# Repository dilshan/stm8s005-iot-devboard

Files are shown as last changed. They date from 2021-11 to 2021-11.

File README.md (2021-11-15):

# STM8S005C6T6 Ethernet development board

This is an Ethernet development board based on [STM8S005C6T6](https://www.st.com/resource/en/datasheet/stm8s005c6.pdf), designed specifically for IoT related applications. This development board consists of [ENC28J60](http://ww1.microchip.com/downloads/en/devicedoc/39662c.pdf), 10BASE-T stand-alone Ethernet controller, [CH340G](https://cdn.sparkfun.com/datasheets/Dev/Arduino/Other/CH340DS1.PDF), USB serial interface, 2 LED indicators, and passive buzzer unit.

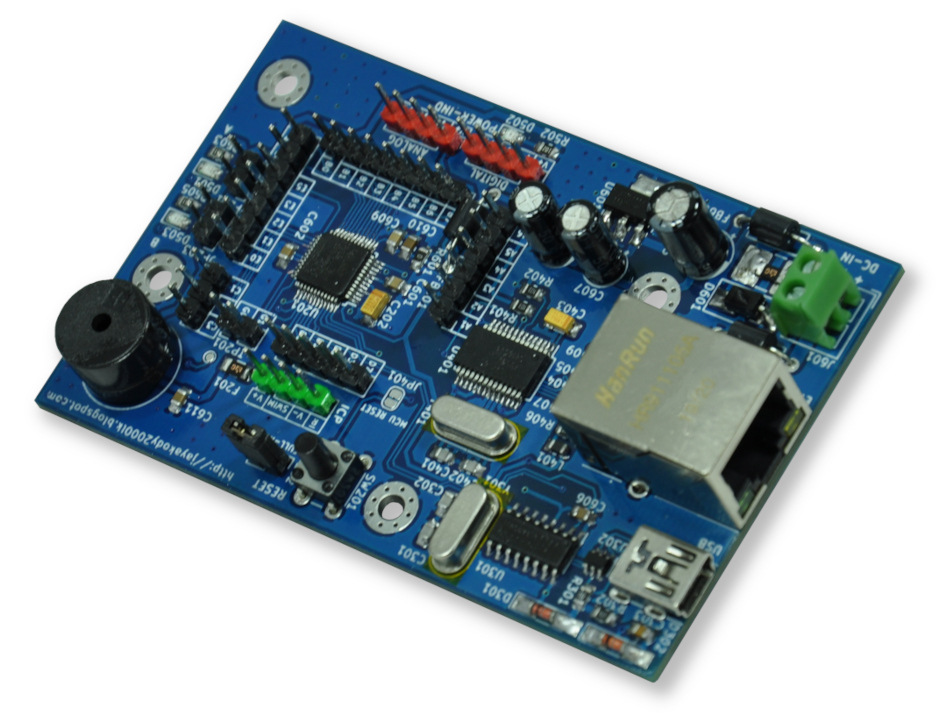
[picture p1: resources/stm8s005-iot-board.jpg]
STM8S005C6T6 Ethernet development board


The firmware framework for this development board has been developed using [SDCC](http://sdcc.sourceforge.net/). To enable IPv4 support, we convert the [EtherCard](https://github.com/njh/EtherCard) driver, which is available for the *Arduino* platform. The current version of this driver supports all other *EtherCard* functions except TCP support.

In the given design, the SPI terminals of the MCU are connected to the ENC28J60 Ethernet controller. All SPI terminals, such as *MISO* / *PC7*, *MOSI* / *PC6*, and *SCK* / *PC5*, are connected directly to the Ethernet controller. In addition, the *PC4* terminal of the MCU is used as ENC28J60, *CHIP-SELECT*. 

The CH340G USB serial interface is connected to the *UART2* terminals of the MCU. In STM8S005C6T6, the *UART2* is mapped to the *PD6* and *PD5* terminals of the MCU. The USB interface of this development board consists of the jack-sense feature. The jack-sense status can access from *PD7*.

The minor peripherals such as LED indicators and buzzer are connected to the *PORTD* of the MCU. The LED indicators are connected to terminals *PD0* and *PD1* and can be activated or deactivated via jumpers. The passive buzzer is connected to *PD4* and can run through the STM8 beep sound generator unit.

All peripherals of this development board are powered by a 3.3V supply. The recommended supply voltage for this development board is  5V to 9V.

In addition to the STM8S005C6T6, this development board supports the following STM8 series, LQFP48 packaged microcontrollers: [STM8S007C8T6](https://www.st.com/resource/en/datasheet/stm8s007c8.pdf), [STM8S207C8T6](https://www.st.com/resource/en/datasheet/stm8s207c8.pdf), and [STM8S105C6T6](https://www.st.com/resource/en/datasheet/stm8s105c6.pdf).

The schematic and PCB design of this project is released under the terms of [CERN-OHL-W Version 2.0](https://ohwr.org/cern_ohl_w_v2.pdf). The firmware framework is released under the terms of the [GNU GPL 2.0](https://github.com/dilshan/stm8s005-iot-devboard/blob/main/LICENSE) license.

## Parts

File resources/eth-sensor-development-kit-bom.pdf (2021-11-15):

Part ID | Value | Quantity
BZ501 | 12mm x 9.5mm Passive Buzzer | 1
| 0.1MFD – 0805 SMD Capacitor
| | 11
C202 | 1MFD / 10V – 1206 SMD Tantalum Capacitor | 1
C301, C302, C401, C402 | 22pF – 0805 SMD Capacitor | 4
C303, C304 | 0.01MFD – 0805 SMD Capacitor | 2
C403 | 10MFD / 10V – 1206 SMD Tantalum Capacitor | 1
C605 | | 1
C607, C608 | 10MFD / 25V – THT Radial Capacitor | 2
C610 | 1MFD / 10V – 0805 SMD Capacitor | 1
D301, D302 | 1N4148 – SMD MiniMELF | 2
D501 | LED (Green) – 0805 SMD | 1
D502 | LED (Red) – 0805 SMD | 1
D503 | LED (Yellow) – 0805 SMD | 1
D601 | SS24 – SMD SMB | 1
F201 | 100mA – 1206 SMD Polyfuse | 1
F601 | 500mA – 2816 SMD Polyfuse | 1
FB601, FB602, FB603 | 6.6mm – THT Axial Ferrite Bead | 3
J201 | 2-Pin – 2.54mm Female Header | 1
J202 | 7-Pin – 2.54mm Female Header | 1
J203 | 8-Pin – 2.54mm Female Header | 1
J204 | 6-Pin – 2.54mm Female Header | 1
J205 | 3-Pin – 2.54mm Female Header | 1
J206 | 5-Pin – 2.54mm Female Header | 1
J207 | 4-Pin – 2.54mm Male Header (Red) | 1
J301 | OMRON XM7D-0512 – USB Type B Mini Socket (THT) | 1
J401 | HR911105A Ethernet Socket with LEDs (THT) | 1
J601 | 2-Pin – 3.5mm Screw Terminal | 1
J602, J603 | 4-Pin – 2.54mm Male Header (Blue) | 2
JP201, JP202, JP203 | 2-Pin – 2.54mm Male Header | 3
L401 | 10uH – 0805 SMD Inductor | 1
Q501, Q502 | 2N7002 | 2
Q503 | MMBT3904 | 1
R201, R302, R401, R402 | 10K – 0805 SMD Resistor | 4
R301 | 6.8K – 0805 SMD Resistor | 1
R303, R403, R404, R502 | 1K – 0805 SMD Resistor | 4
R405 | 2.7K – 0805 SMD Resistor | 1
R406, R407, R408, R409 | 50R – 0805 SMD Resistor | 4
R501, R504 | 1M – 0805 SMD Resistor | 2
R503, R505 | 560R – 0805 SMD Resistor | 2
R506 | 2.2K – 0805 SMD Resistor | 1
R601 | 0R – 0805 SMD Resistor | 1
SW201 | 6mm x 6mm Tactile Switch | 1
U201 | STM8S005C6T6 | 1
U301 | CH340G | 1
U302 | USBLC6-2SC6 | 1
U401 | ENC28J60I-SS | 1
U601 | AMS1117-3.3 | 1
Y301 | 12MHz – HC49 Crystal | 1
Y401 | 25MHz – HC49 Crystal | 1

C201, C404, C405, C501, C601, C602, C603, C604, C606, C609, C611

100MFD / 25V – THT Radial Capacitor

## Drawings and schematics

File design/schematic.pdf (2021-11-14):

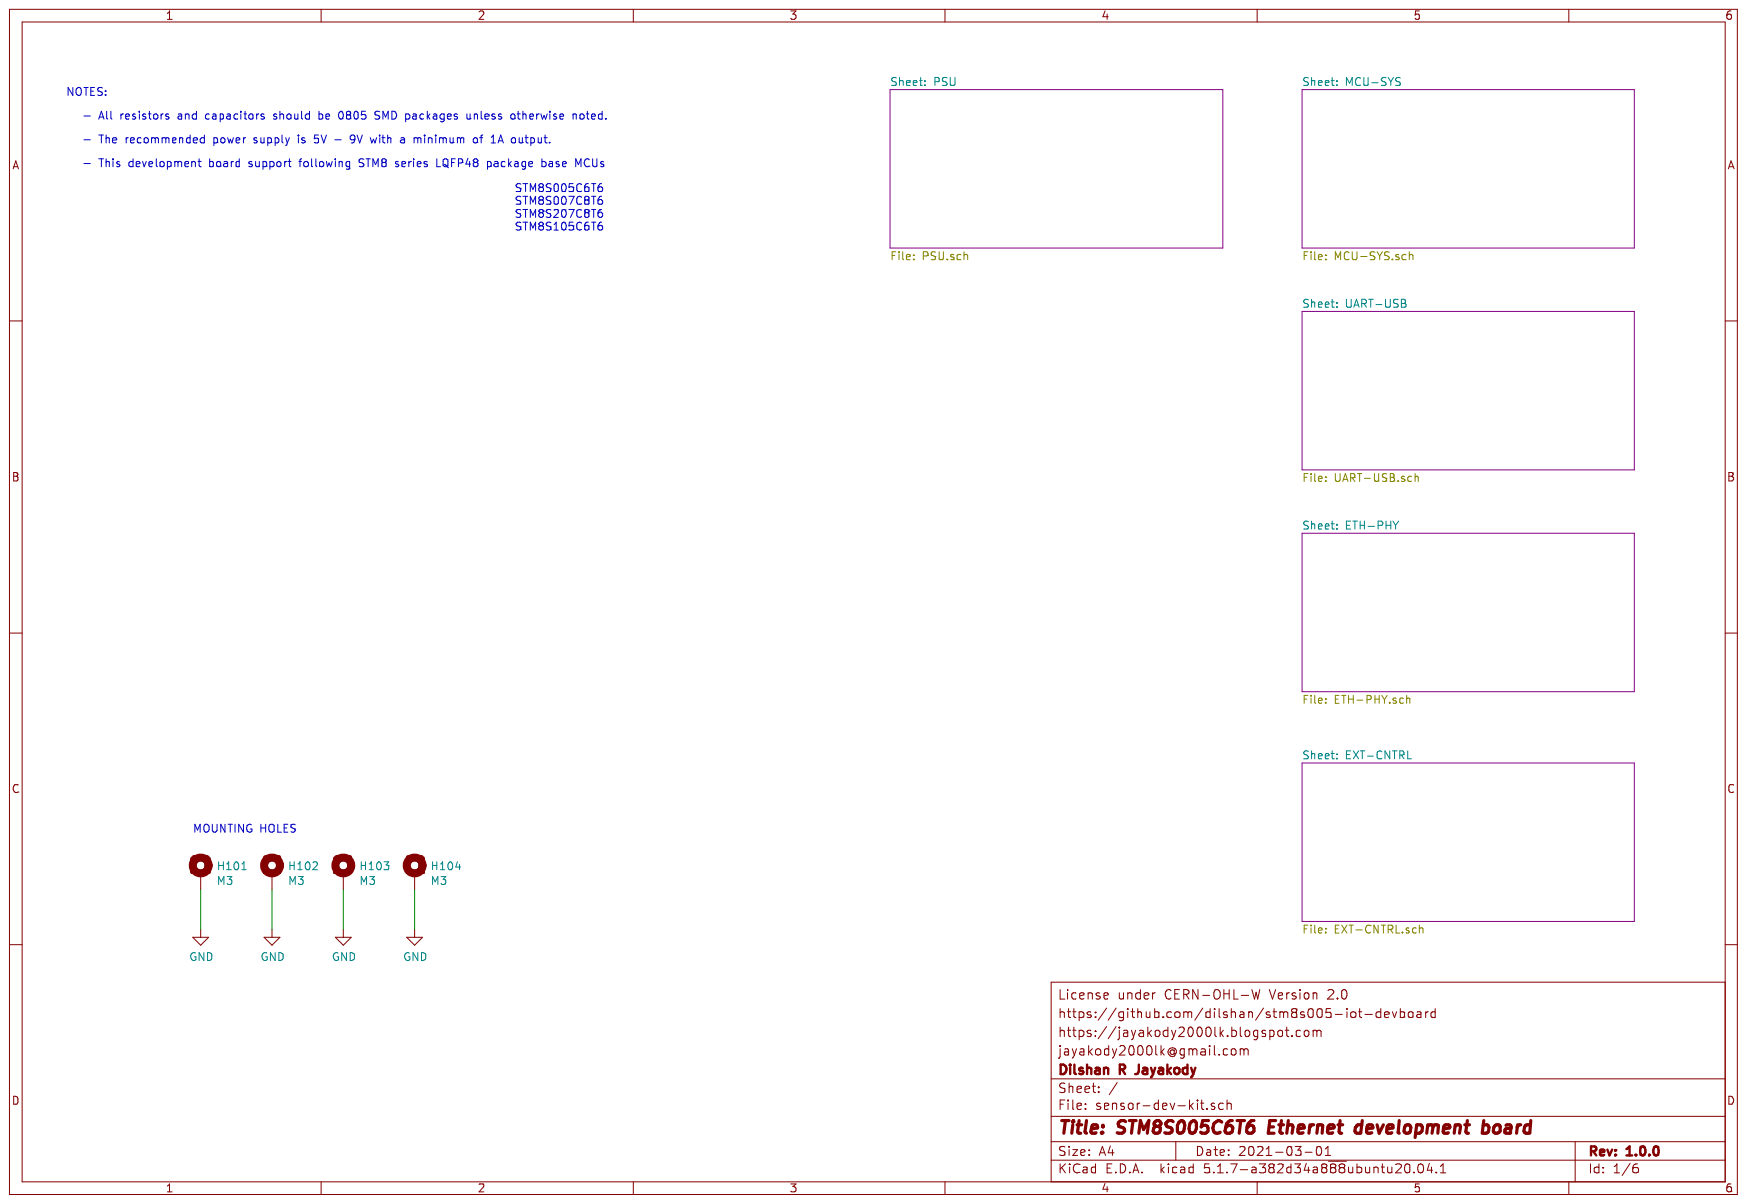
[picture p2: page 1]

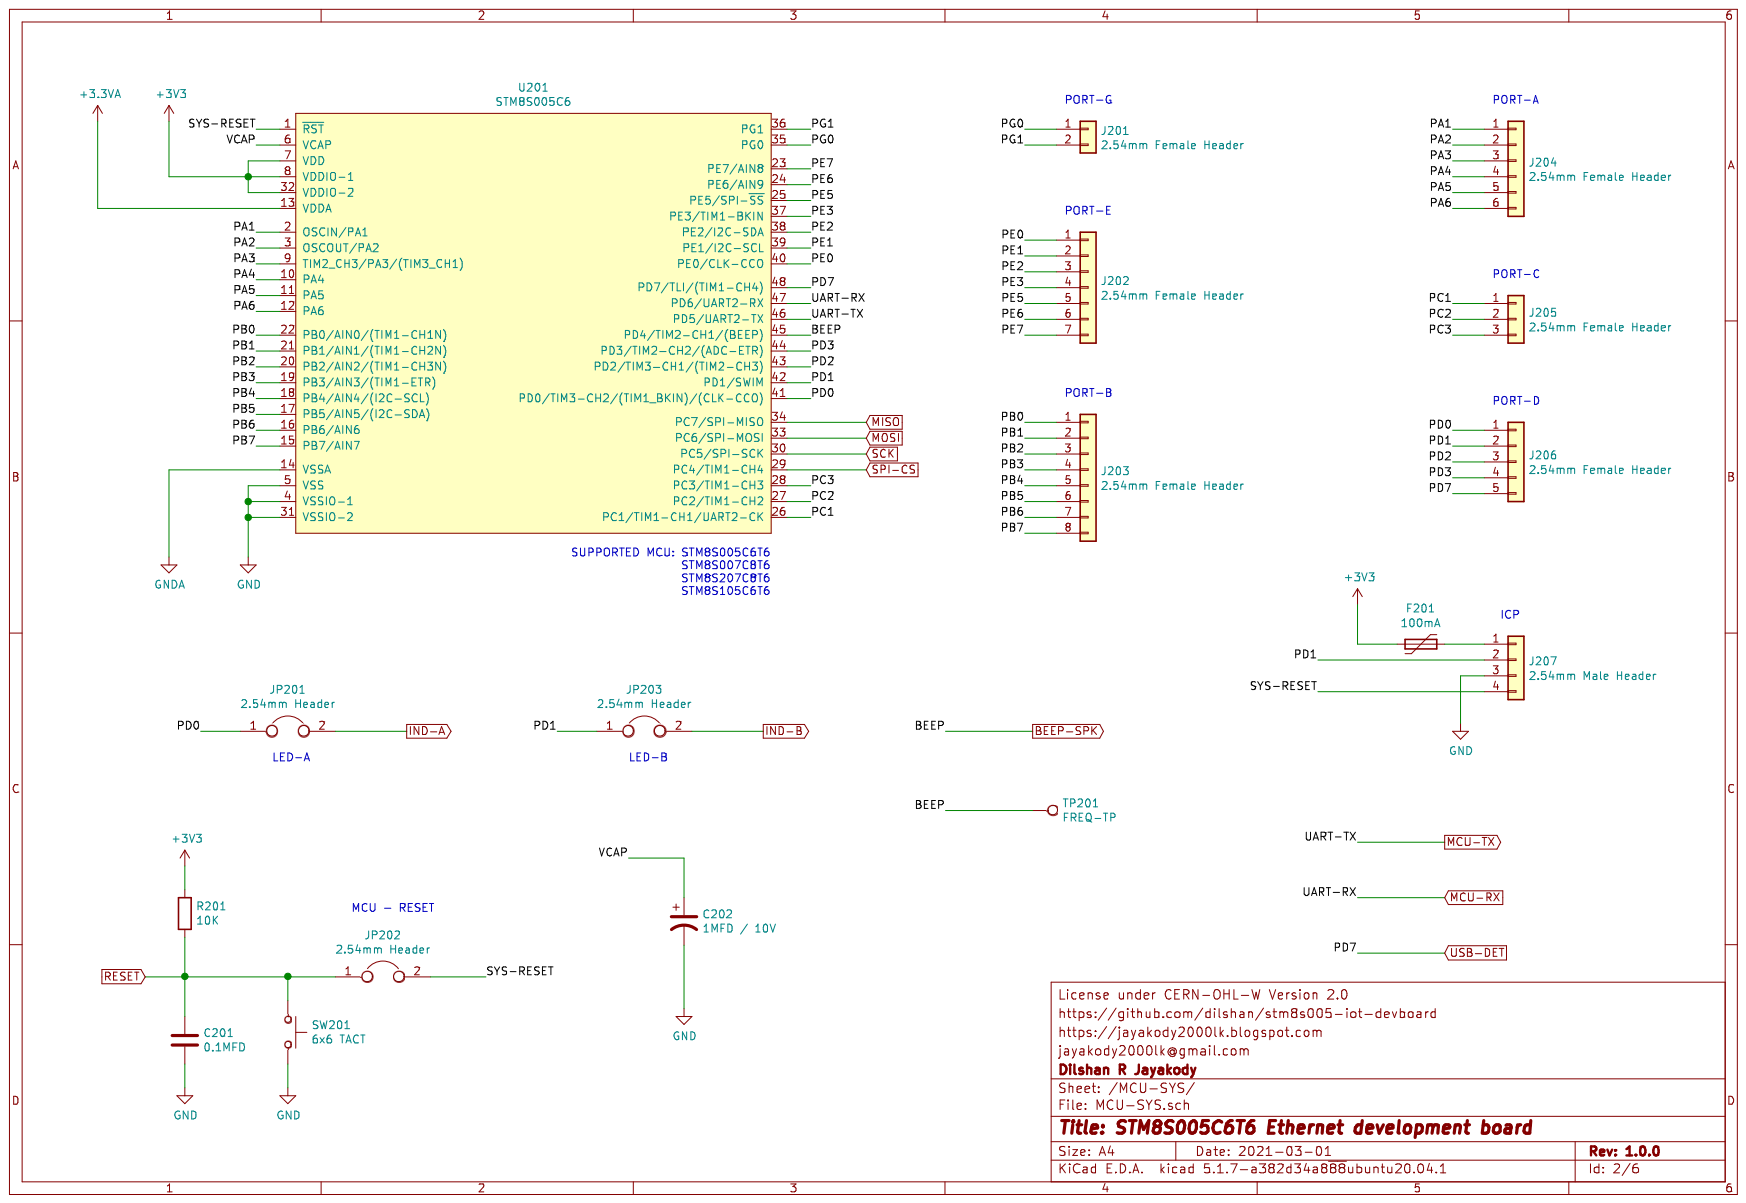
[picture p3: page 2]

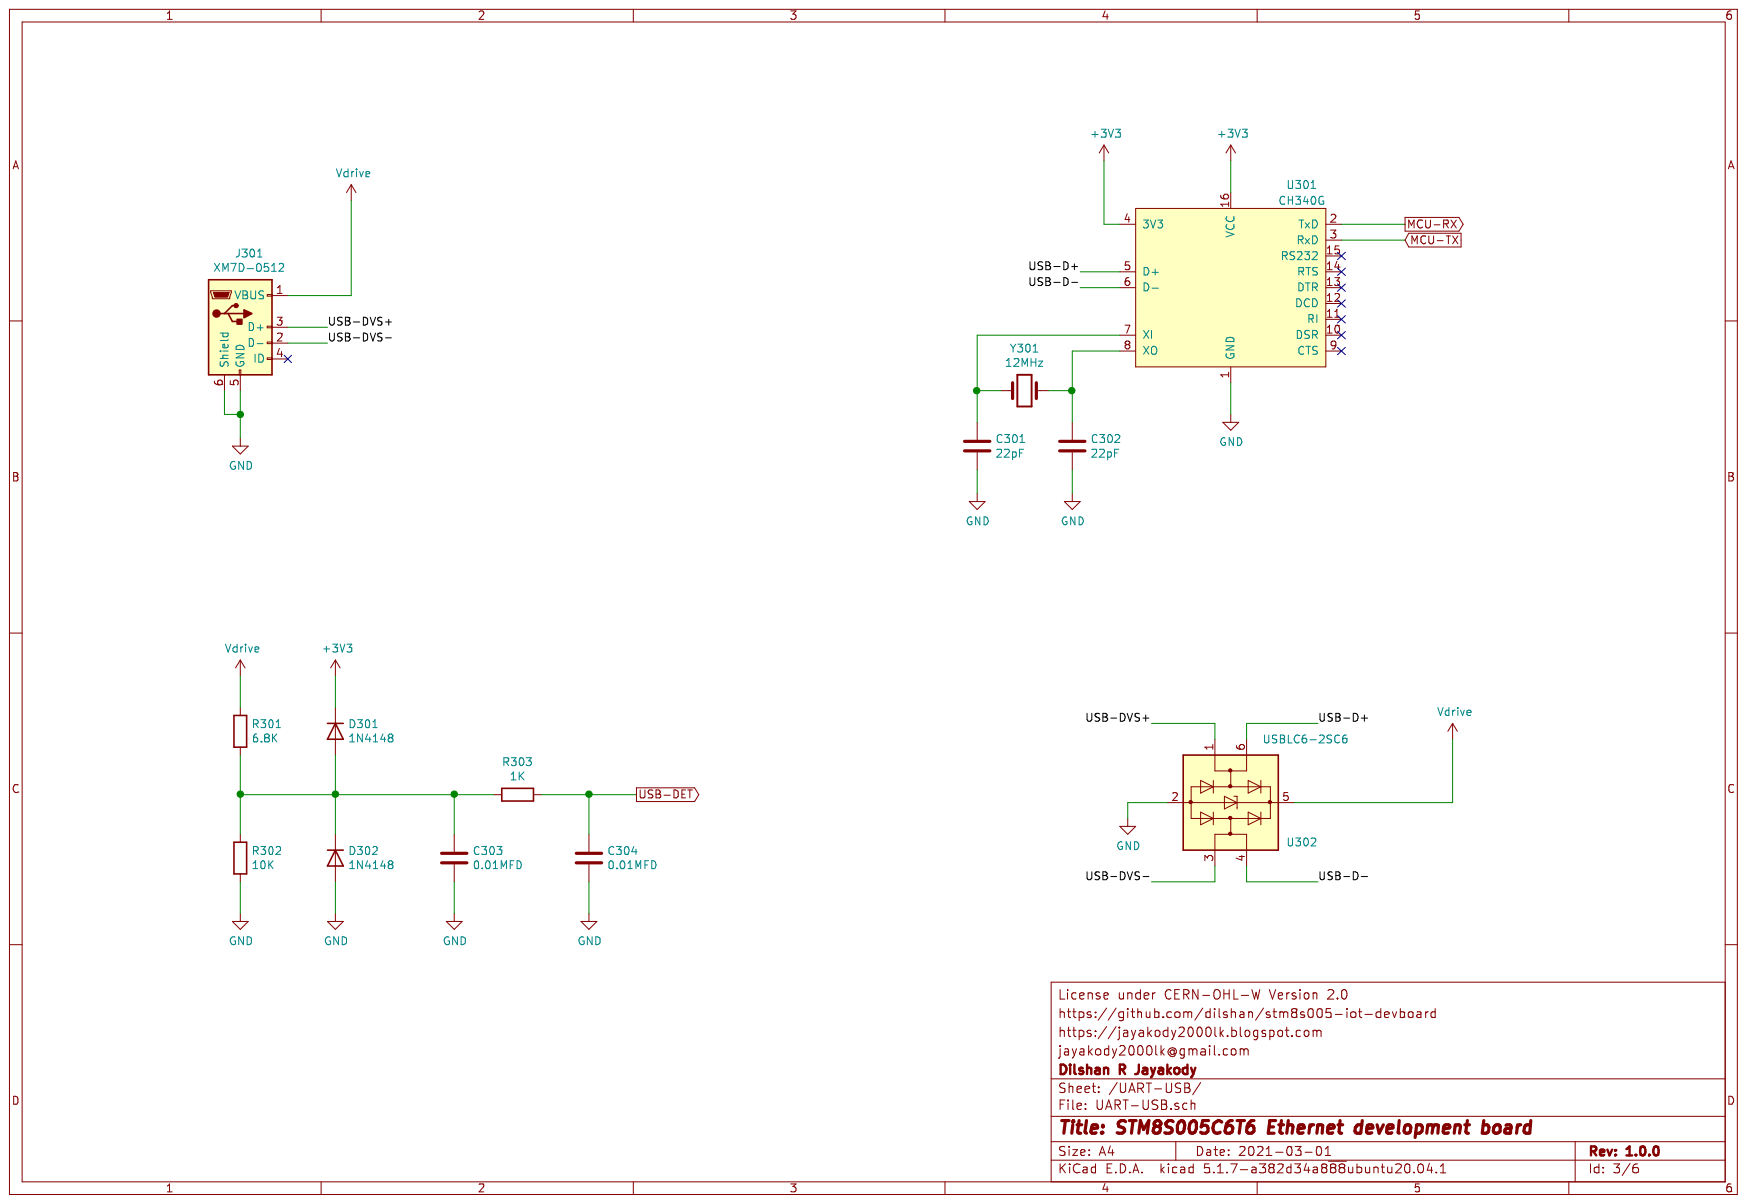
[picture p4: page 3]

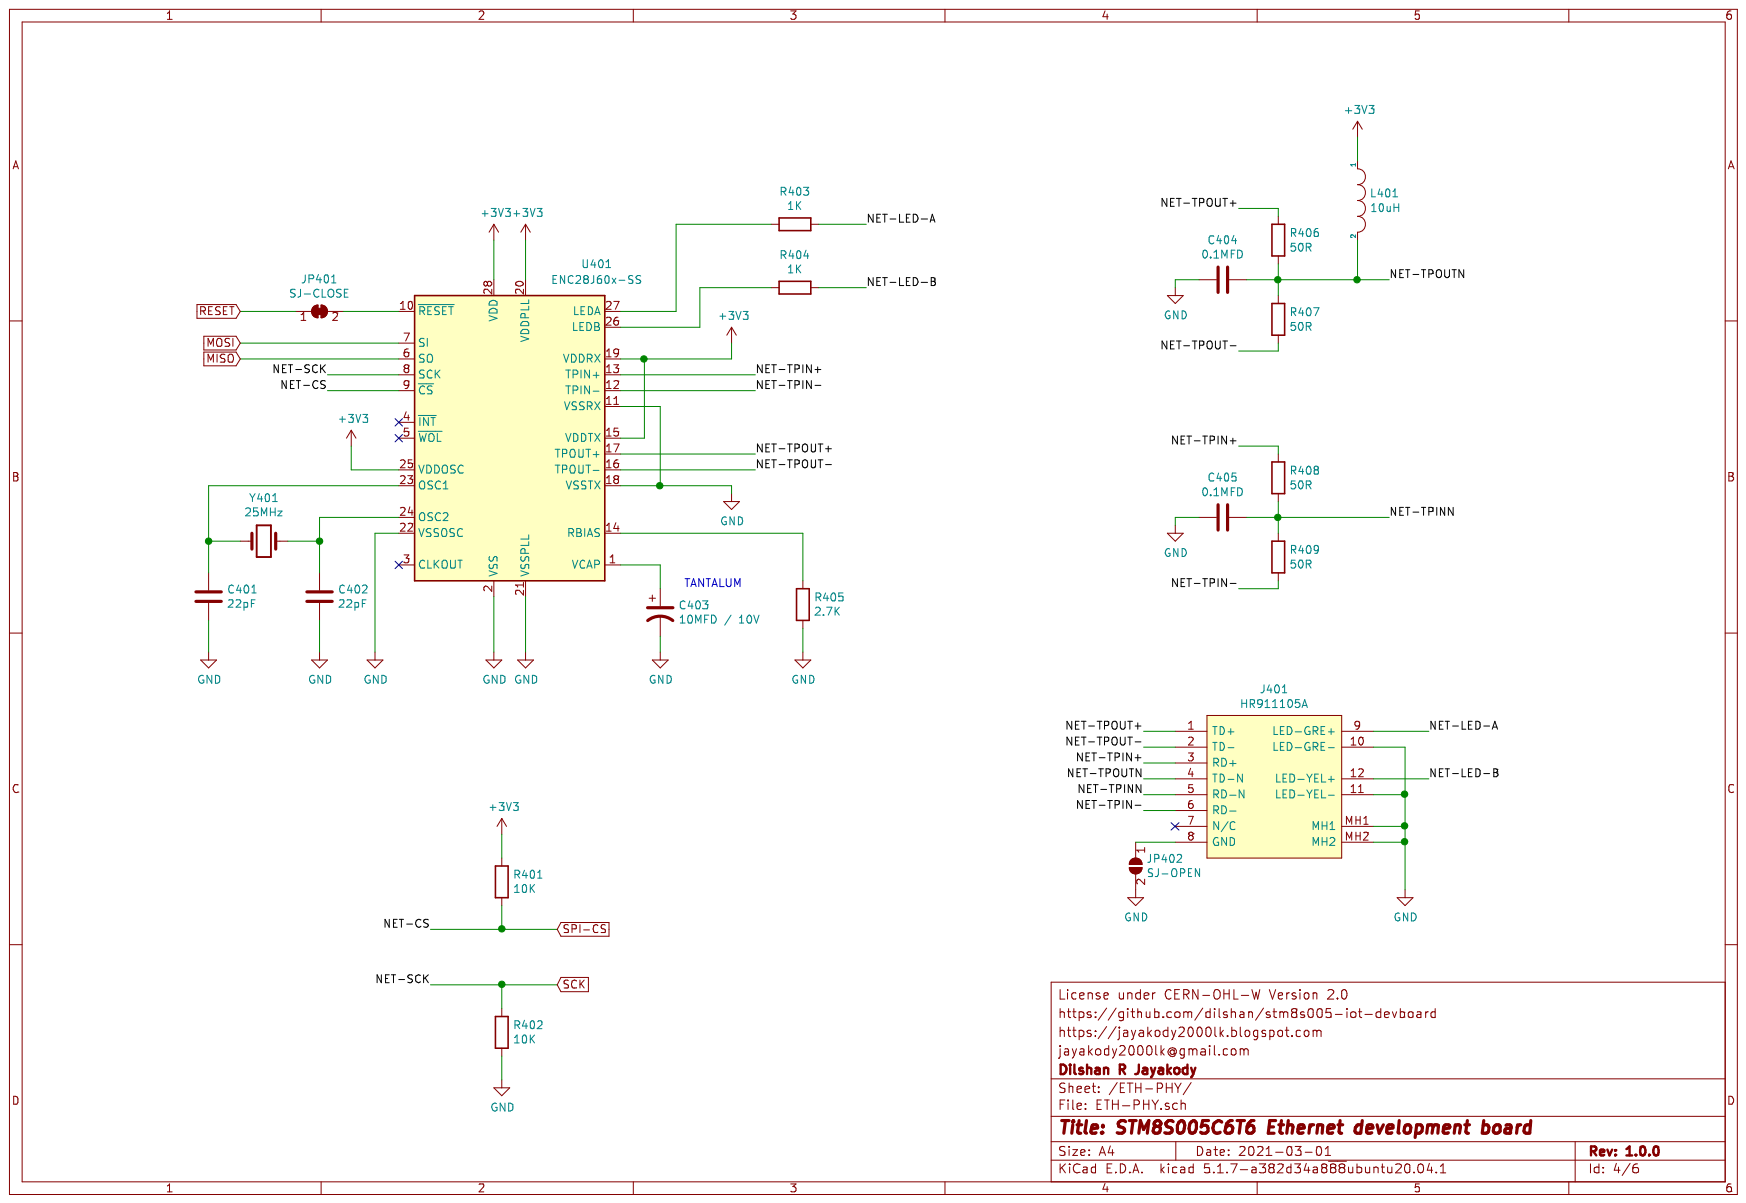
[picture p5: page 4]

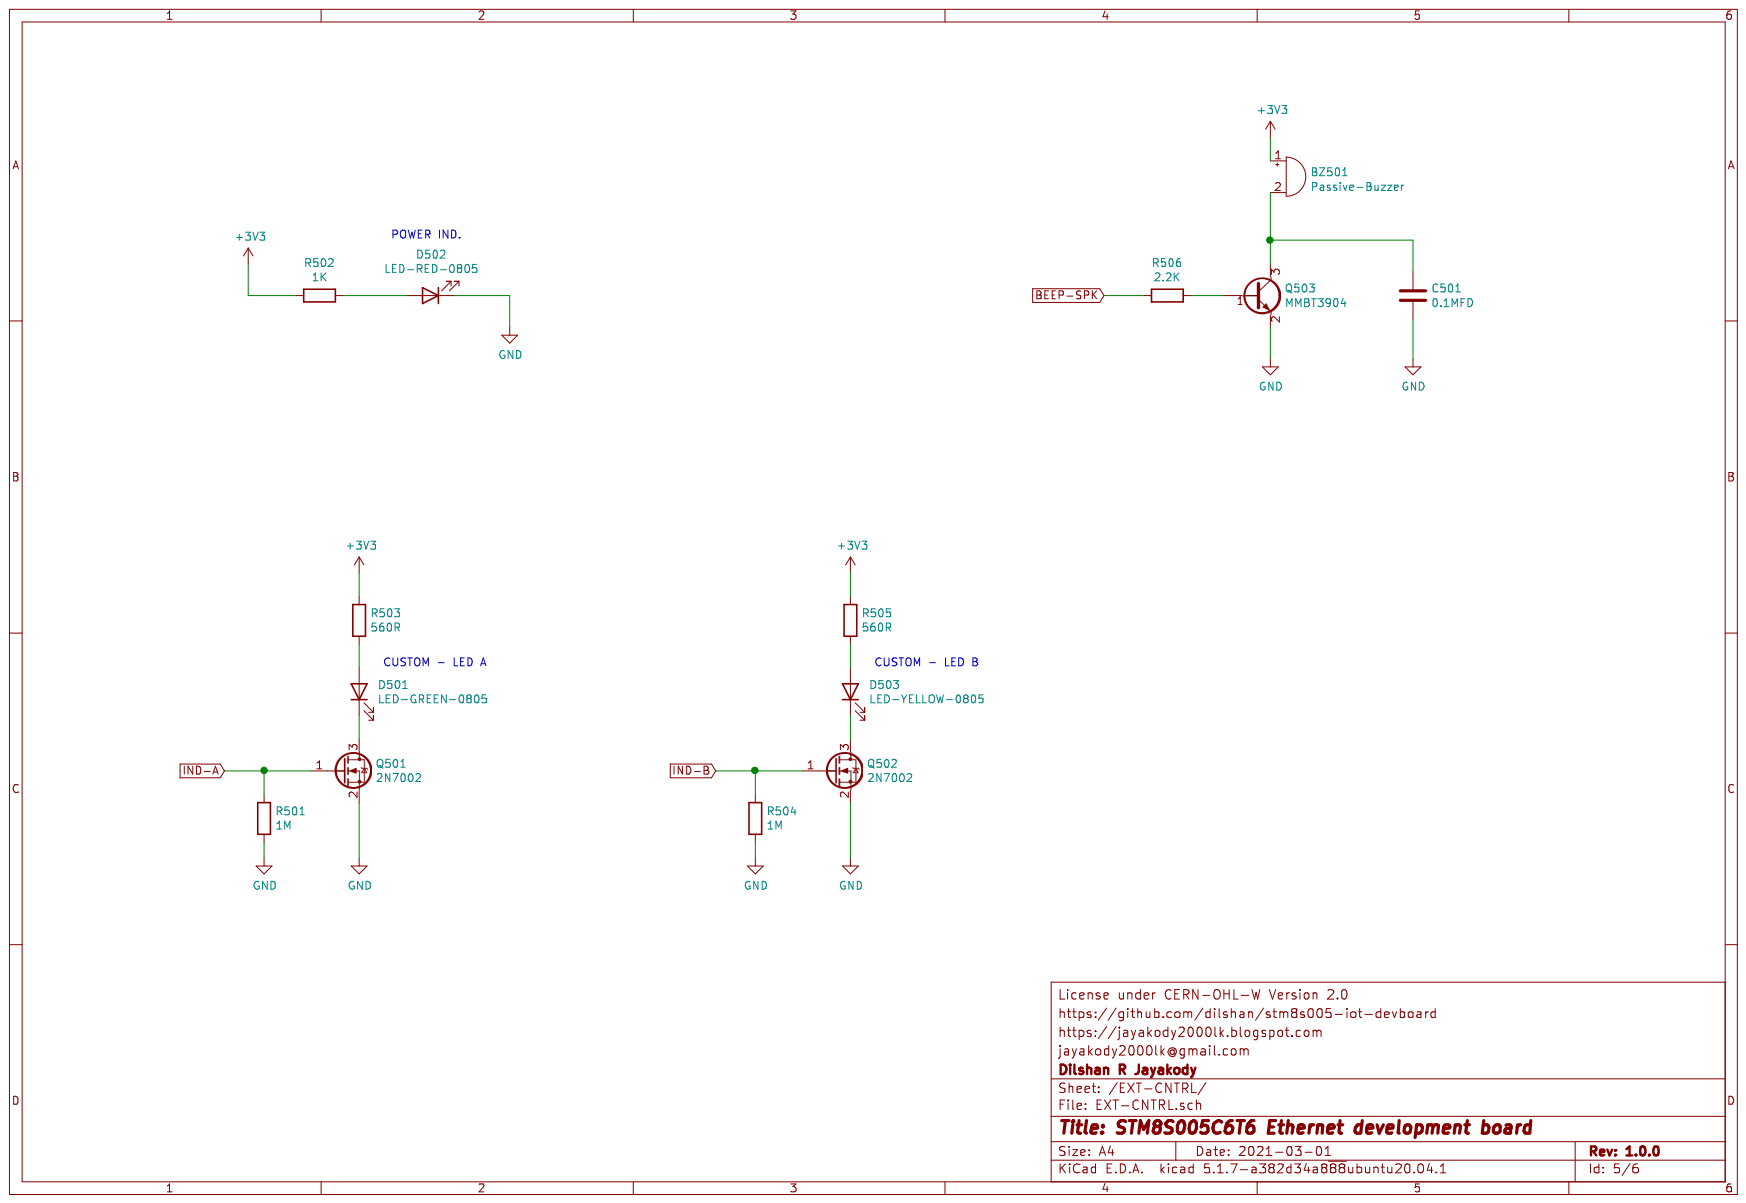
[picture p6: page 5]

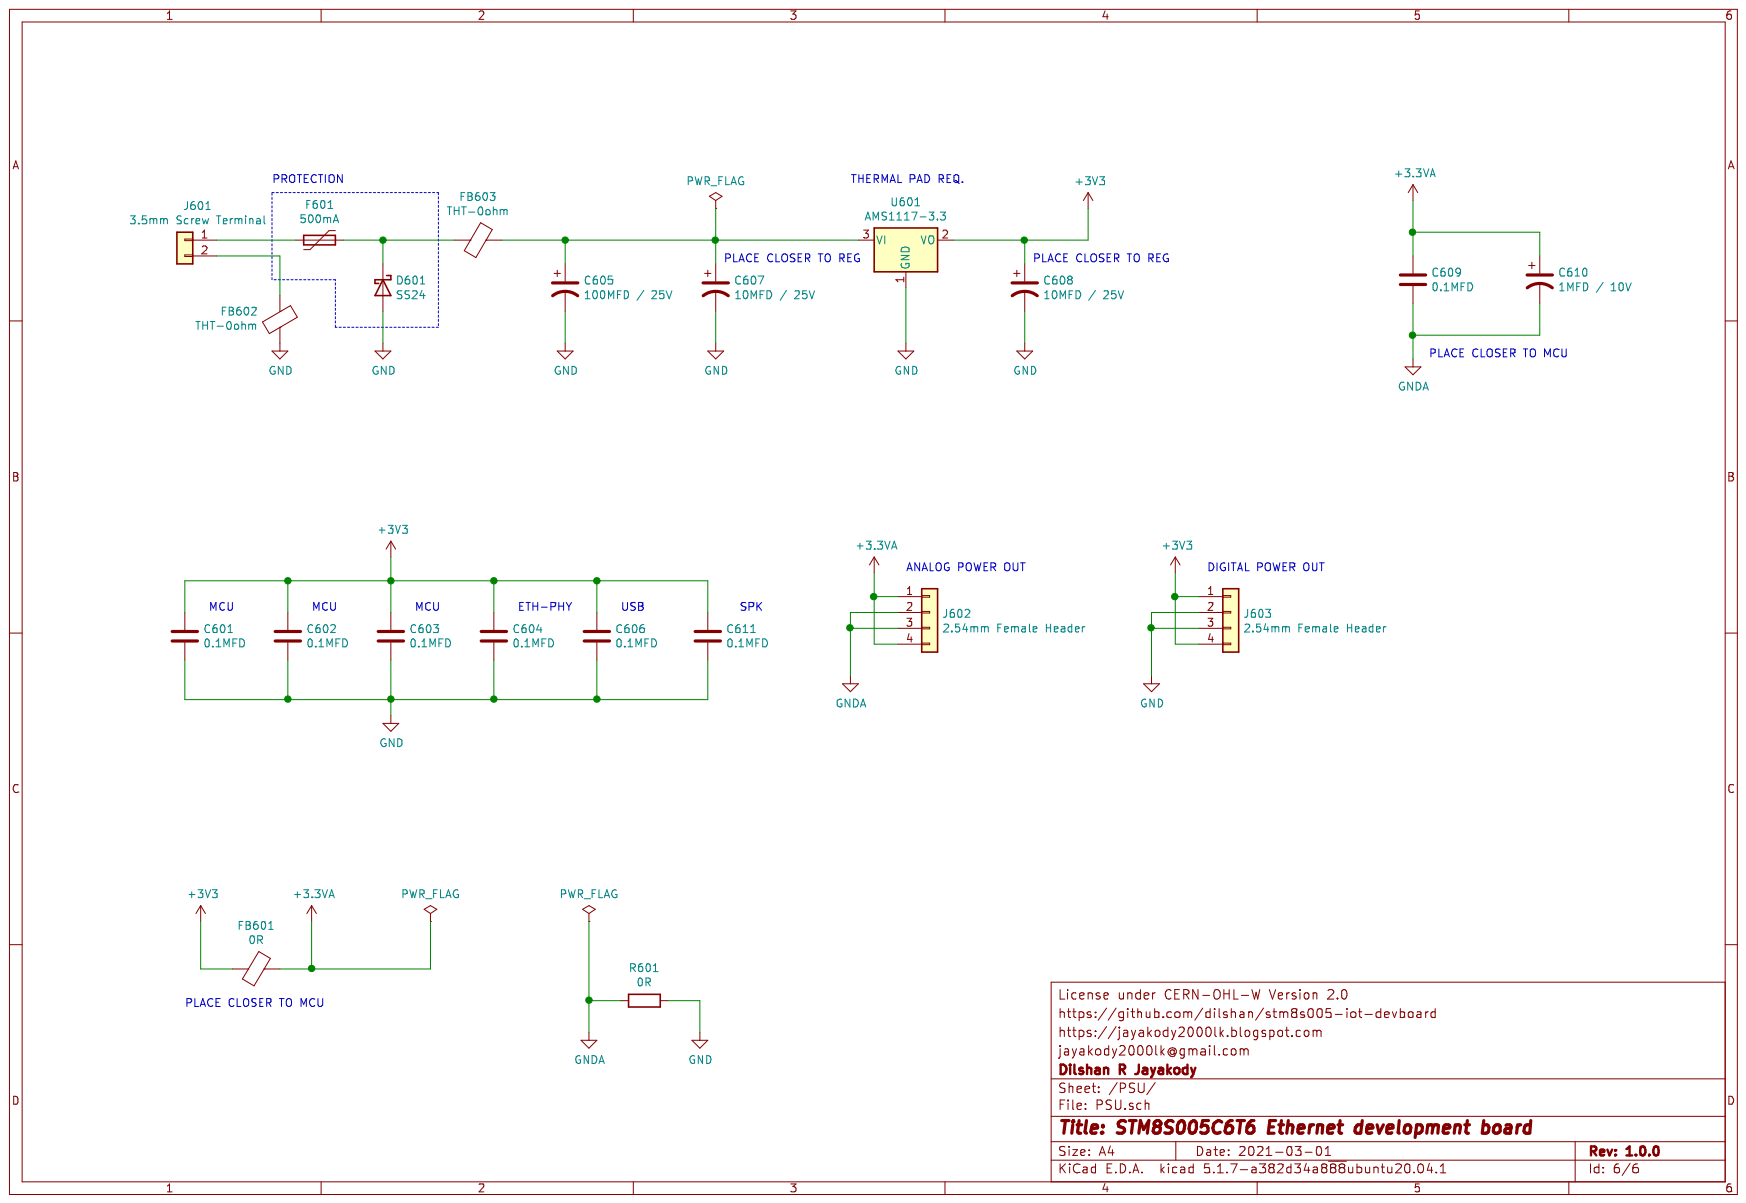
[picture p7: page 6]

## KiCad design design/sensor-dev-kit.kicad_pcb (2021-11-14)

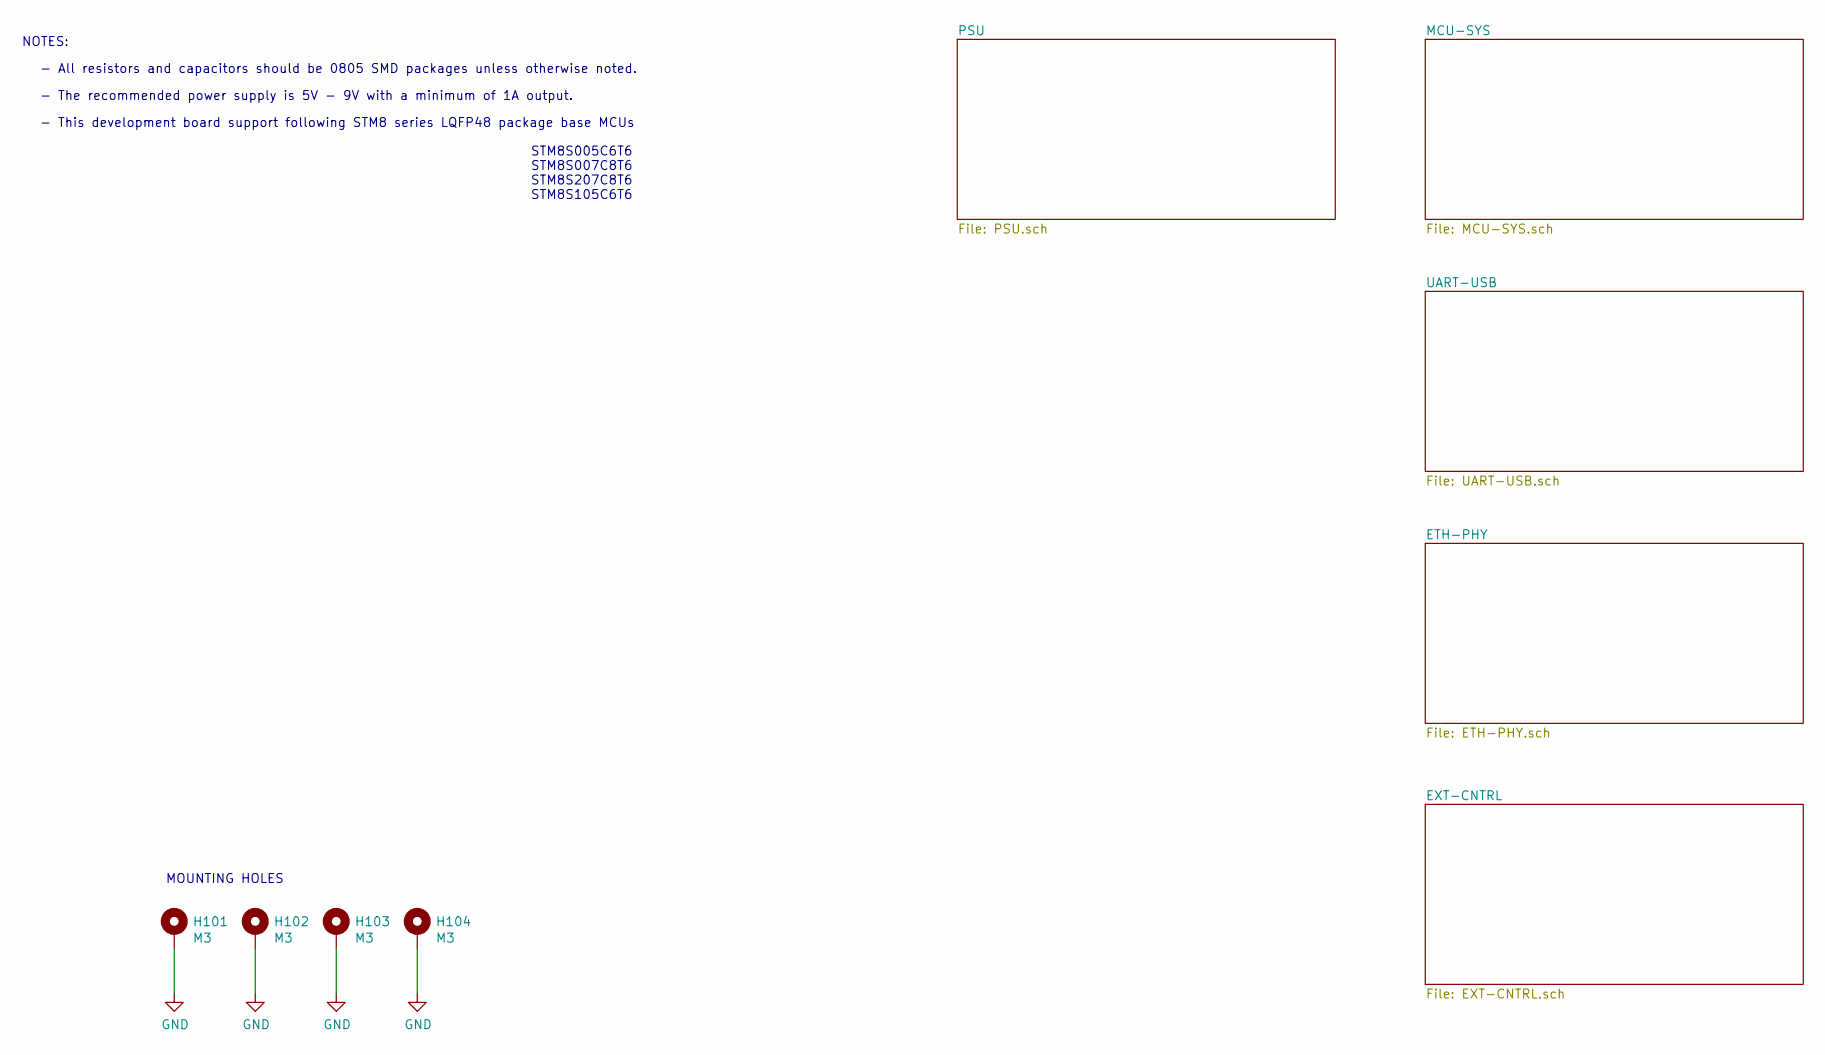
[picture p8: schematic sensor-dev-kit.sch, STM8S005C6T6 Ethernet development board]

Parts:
H101, H102, H103, H104: M3; MountingHole_3.2mm_M3_Pad_Via

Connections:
GND: H101.1, H102.1, H103.1, H104.1; also elsewhere on the board

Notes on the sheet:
NOTES:
- All resistors and capacitors should be 0805 SMD packages unless otherwise noted.
- The recommended power supply is 5V - 9V with a minimum of 1A output.
STM8S005C6T6 STM8S007C8T6 STM8S207C8T6 STM8S105C6T6
- This development board support following STM8 series LQFP48 package base MCUs
MOUNTING HOLES

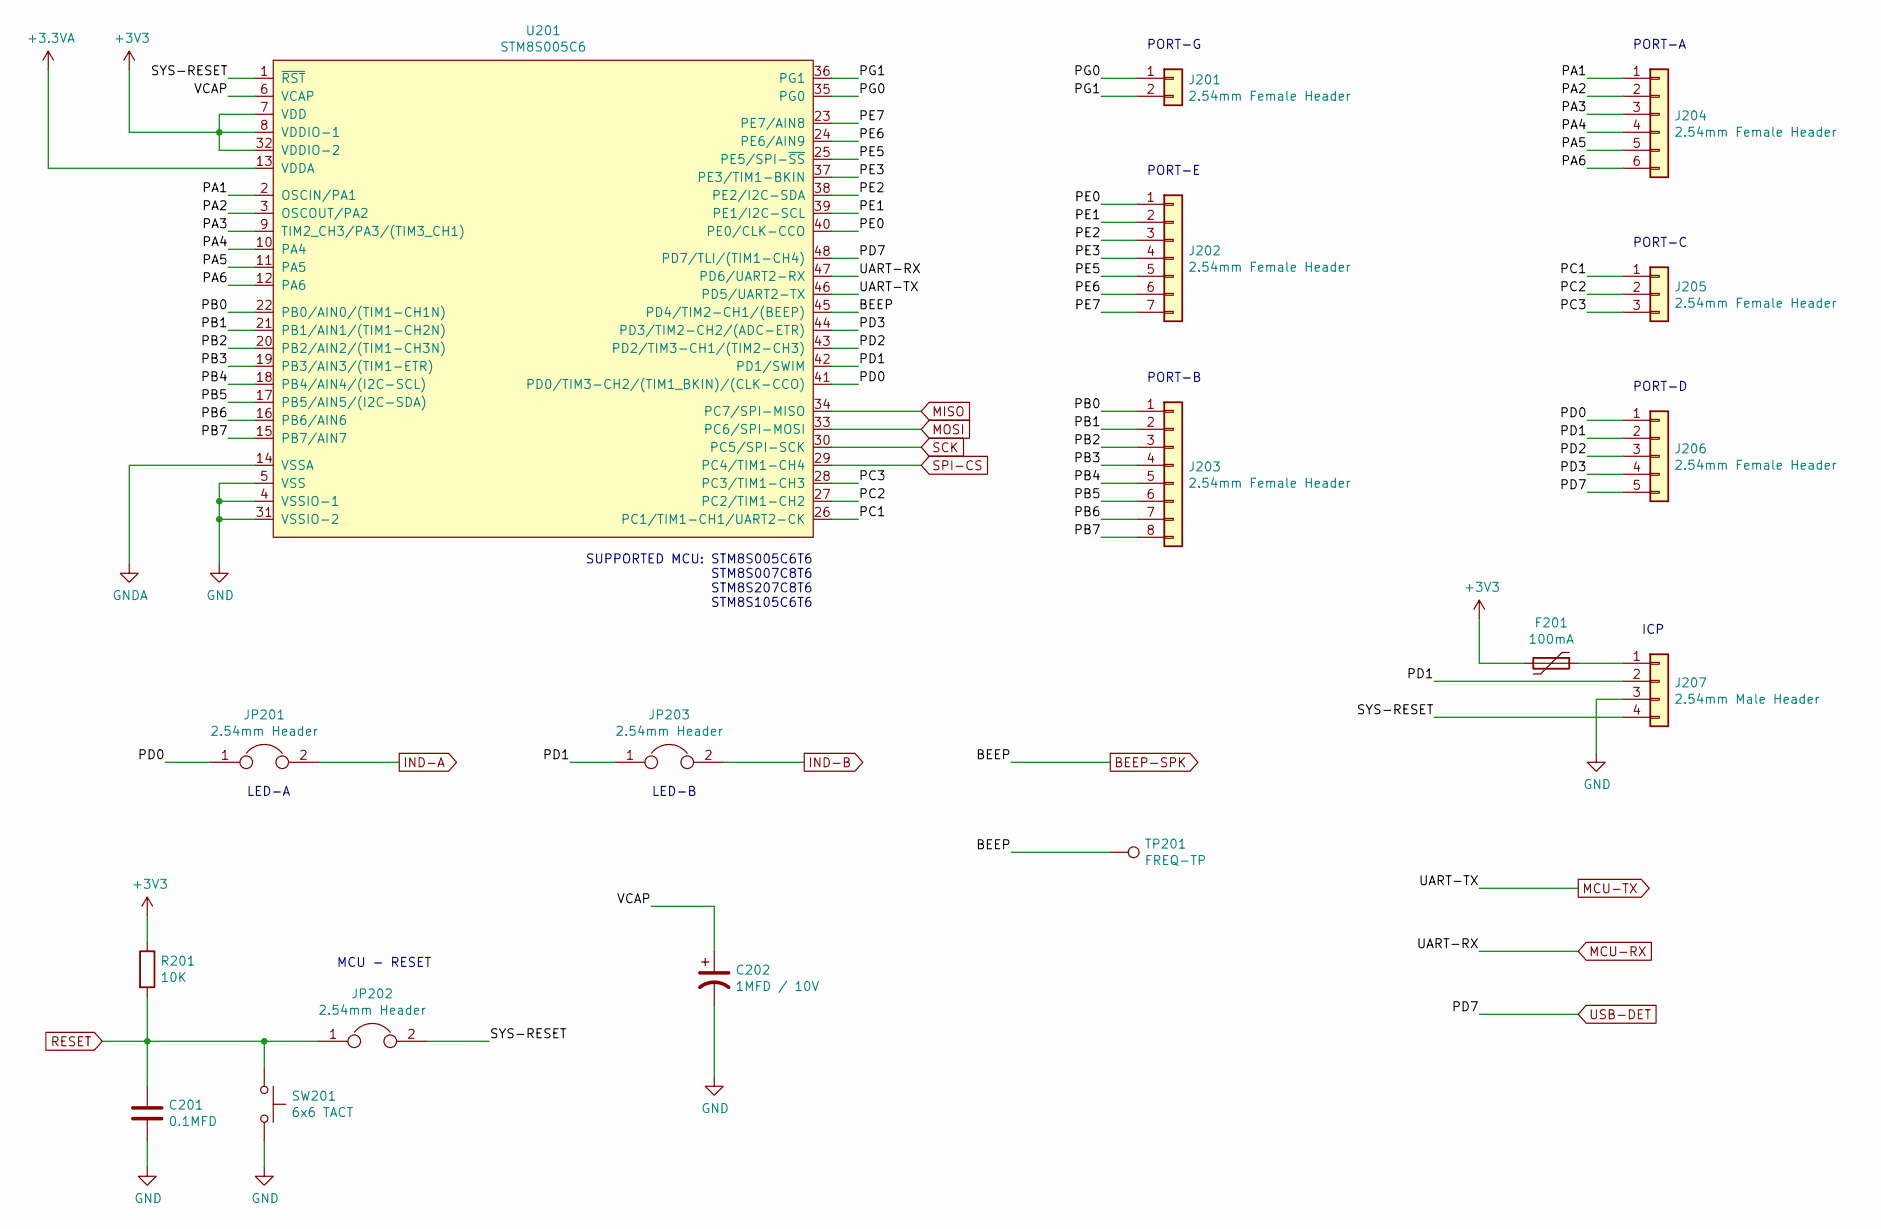
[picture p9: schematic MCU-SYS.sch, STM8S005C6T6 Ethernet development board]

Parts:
C201: 0.1MFD; C_0805_2012Metric_Pad1.18x1.45mm_HandSolder
C202: 1MFD / 10V; C_1206_3216Metric_Pad1.33x1.80mm_HandSolder
F201: 100mA; Fuse_1206_3216Metric_Pad1.42x1.75mm_HandSolder
J201: 2.54mm Female Header; PinHeader_1x02_P2.54mm_Vertical
J202: 2.54mm Female Header; PinHeader_1x07_P2.54mm_Vertical
J203: 2.54mm Female Header; PinHeader_1x08_P2.54mm_Vertical
J204: 2.54mm Female Header; PinHeader_1x06_P2.54mm_Vertical
J205: 2.54mm Female Header; PinHeader_1x03_P2.54mm_Vertical
J206: 2.54mm Female Header; PinHeader_1x05_P2.54mm_Vertical
J207: 2.54mm Male Header; PinHeader_1x04_P2.54mm_Vertical
JP201, JP202, JP203: 2.54mm Header; PinHeader_1x02_P2.54mm_Vertical
R201: 10K; R_0805_2012Metric_Pad1.20x1.40mm_HandSolder
SW201: 6x6 TACT; SW_PUSH_6mm
TP201: FREQ-TP; TestPoint_Pad_D1.0mm
U201: STM8S005C6; LQFP-48_7x7mm_P0.5mm

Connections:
+3.3VA: U201.13 (VDDA); also elsewhere on the board
+3V3: F201.2, R201.1, U201.7 (VDD), U201.8 (VDDIO-1), U201.32 (VDDIO-2); also elsewhere on the board
/MCU-SYS/PA1: J204.1, U201.2 (OSCIN/PA1)
/MCU-SYS/PA2: J204.2, U201.3 (OSCOUT/PA2)
/MCU-SYS/PA3: J204.3, U201.9 (TIM2_CH3/PA3/(TIM3_CH1))
/MCU-SYS/PA4: J204.4, U201.10 (PA4)
/MCU-SYS/PA5: J204.5, U201.11 (PA5)
/MCU-SYS/PA6: J204.6, U201.12 (PA6)
/MCU-SYS/PB0: J203.1, U201.22 (PB0/AIN0/(TIM1-CH1N))
/MCU-SYS/PB1: J203.2, U201.21 (PB1/AIN1/(TIM1-CH2N))
/MCU-SYS/PB2: J203.3, U201.20 (PB2/AIN2/(TIM1-CH3N))
/MCU-SYS/PB3: J203.4, U201.19 (PB3/AIN3/(TIM1-ETR))
/MCU-SYS/PB4: J203.5, U201.18 (PB4/AIN4/(I2C-SCL))
/MCU-SYS/PB5: J203.6, U201.17 (PB5/AIN5/(I2C-SDA))
/MCU-SYS/PB6: J203.7, U201.16 (PB6/AIN6)
/MCU-SYS/PB7: J203.8, U201.15 (PB7/AIN7)
/MCU-SYS/PC1: J205.1, U201.26 (PC1/TIM1-CH1/UART2-CK)
/MCU-SYS/PC2: J205.2, U201.27 (PC2/TIM1-CH2)
/MCU-SYS/PC3: J205.3, U201.28 (PC3/TIM1-CH3)
/MCU-SYS/PD0: J206.1, JP201.1, U201.41 (PD0/TIM3-CH2/(TIM1_BKIN)/(CLK-CCO))
/MCU-SYS/PD1: J206.2, J207.2, JP203.1, U201.42 (PD1/SWIM)
/MCU-SYS/PD2: J206.3, U201.43 (PD2/TIM3-CH1/(TIM2-CH3))
/MCU-SYS/PD3: J206.4, U201.44 (PD3/TIM2-CH2/(ADC-ETR))
/MCU-SYS/PE0: J202.1, U201.40 (PE0/CLK-CCO)
/MCU-SYS/PE1: J202.2, U201.39 (PE1/I2C-SCL)
/MCU-SYS/PE2: J202.3, U201.38 (PE2/I2C-SDA)
/MCU-SYS/PE3: J202.4, U201.37 (PE3/TIM1-BKIN)
/MCU-SYS/PE5: J202.5, U201.25 (PE5/SPI-~SS)
/MCU-SYS/PE6: J202.6, U201.24 (PE6/AIN9)
/MCU-SYS/PE7: J202.7, U201.23 (PE7/AIN8)
/MCU-SYS/PG0: J201.1, U201.35 (PG0)
/MCU-SYS/PG1: J201.2, U201.36 (PG1)
/MCU-SYS/SYS-RESET: J207.4, JP202.2, U201.1 (~RST)
/MCU-SYS/VCAP: C202.1, U201.6 (VCAP)
BEEP-SPK: TP201.1, U201.45 (PD4/TIM2-CH1/(BEEP)); also elsewhere on the board
GND: C201.2, C202.2, J207.3, SW201.2, U201.4 (VSSIO-1), U201.5 (VSS), U201.31 (VSSIO-2); also elsewhere on the board
GNDA: U201.14 (VSSA); also elsewhere on the board
IND-A: JP201.2; also elsewhere on the board
IND-B: JP203.2; also elsewhere on the board
MCU-RX: U201.47 (PD6/UART2-RX); also elsewhere on the board
MCU-TX: U201.46 (PD5/UART2-TX); also elsewhere on the board
MISO: U201.34 (PC7/SPI-MISO); also elsewhere on the board
MOSI: U201.33 (PC6/SPI-MOSI); also elsewhere on the board
unnamed: F201.1, J207.1
RESET: C201.1, JP202.1, R201.2, SW201.1; also elsewhere on the board
SCK: U201.30 (PC5/SPI-SCK); also elsewhere on the board
SPI-CS: U201.29 (PC4/TIM1-CH4); also elsewhere on the board
USB-DET: J206.5, U201.48 (PD7/TLI/(TIM1-CH4)); also elsewhere on the board

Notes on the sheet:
PORT-G
PORT-E
PORT-B
PORT-A
PORT-C
PORT-D
ICP
LED-A
LED-B
MCU - RESET
SUPPORTED MCU: STM8S005C6T6 STM8S007C8T6 STM8S207C8T6 STM8S105C6T6

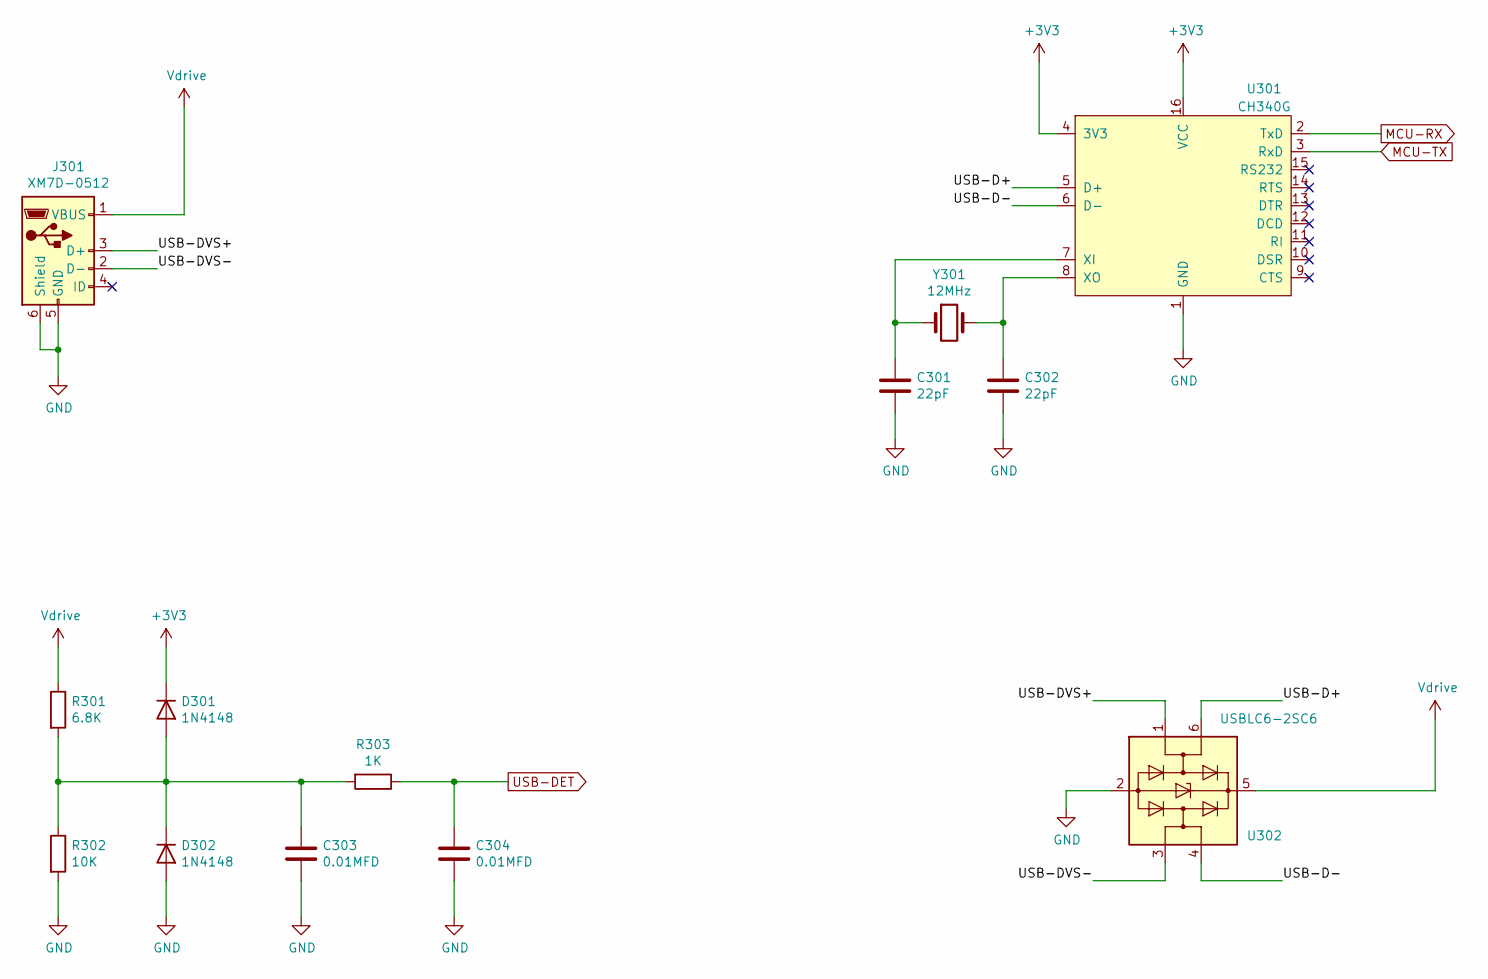
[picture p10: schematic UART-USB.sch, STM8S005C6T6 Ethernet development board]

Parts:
C301, C302: 22pF; C_0805_2012Metric_Pad1.18x1.45mm_HandSolder
C303, C304: 0.01MFD; C_0805_2012Metric_Pad1.18x1.45mm_HandSolder
D301, D302: 1N4148; D_MiniMELF_Handsoldering
J301: XM7D-0512; OMRON_XM7D-0512
R301: 6.8K; R_0805_2012Metric_Pad1.20x1.40mm_HandSolder
R302: 10K; R_0805_2012Metric_Pad1.20x1.40mm_HandSolder
R303: 1K; R_0805_2012Metric_Pad1.20x1.40mm_HandSolder
U301: CH340G; SOP-16_3.9x9.9mm_P1.27mm
U302: USBLC6-2SC6; SOT-23-6
Y301: 12MHz; Crystal_HC49-U_Vertical

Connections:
+3V3: D301.1 (K), U301.4 (3V3), U301.16 (VCC); also elsewhere on the board
/UART-USB/USB-D+: U301.5 (D+), U302.6 (I/O1)
/UART-USB/USB-D-: U301.6 (D-), U302.4 (I/O2)
/UART-USB/USB-DVS+: J301.3 (D+), U302.1 (I/O1)
/UART-USB/USB-DVS-: J301.2 (D-), U302.3 (I/O2)
GND: C301.2, C302.2, C303.2, C304.2, D302.2 (A), J301.5 (GND), J301.6 (Shield), R302.2, U301.1 (GND), U302.2 (GND); also elsewhere on the board
MCU-RX: U301.2 (TxD); also elsewhere on the board
MCU-TX: U301.3 (RxD); also elsewhere on the board
unnamed: C301.1, U301.7 (XI), Y301.1
unnamed: C302.1, U301.8 (XO), Y301.2
unnamed: C303.1, D301.2 (A), D302.1 (K), R301.2, R302.1, R303.2
USB-DET: C304.1, R303.1; also elsewhere on the board
Vdrive: J301.1 (VBUS), R301.1, U302.5 (VBUS)

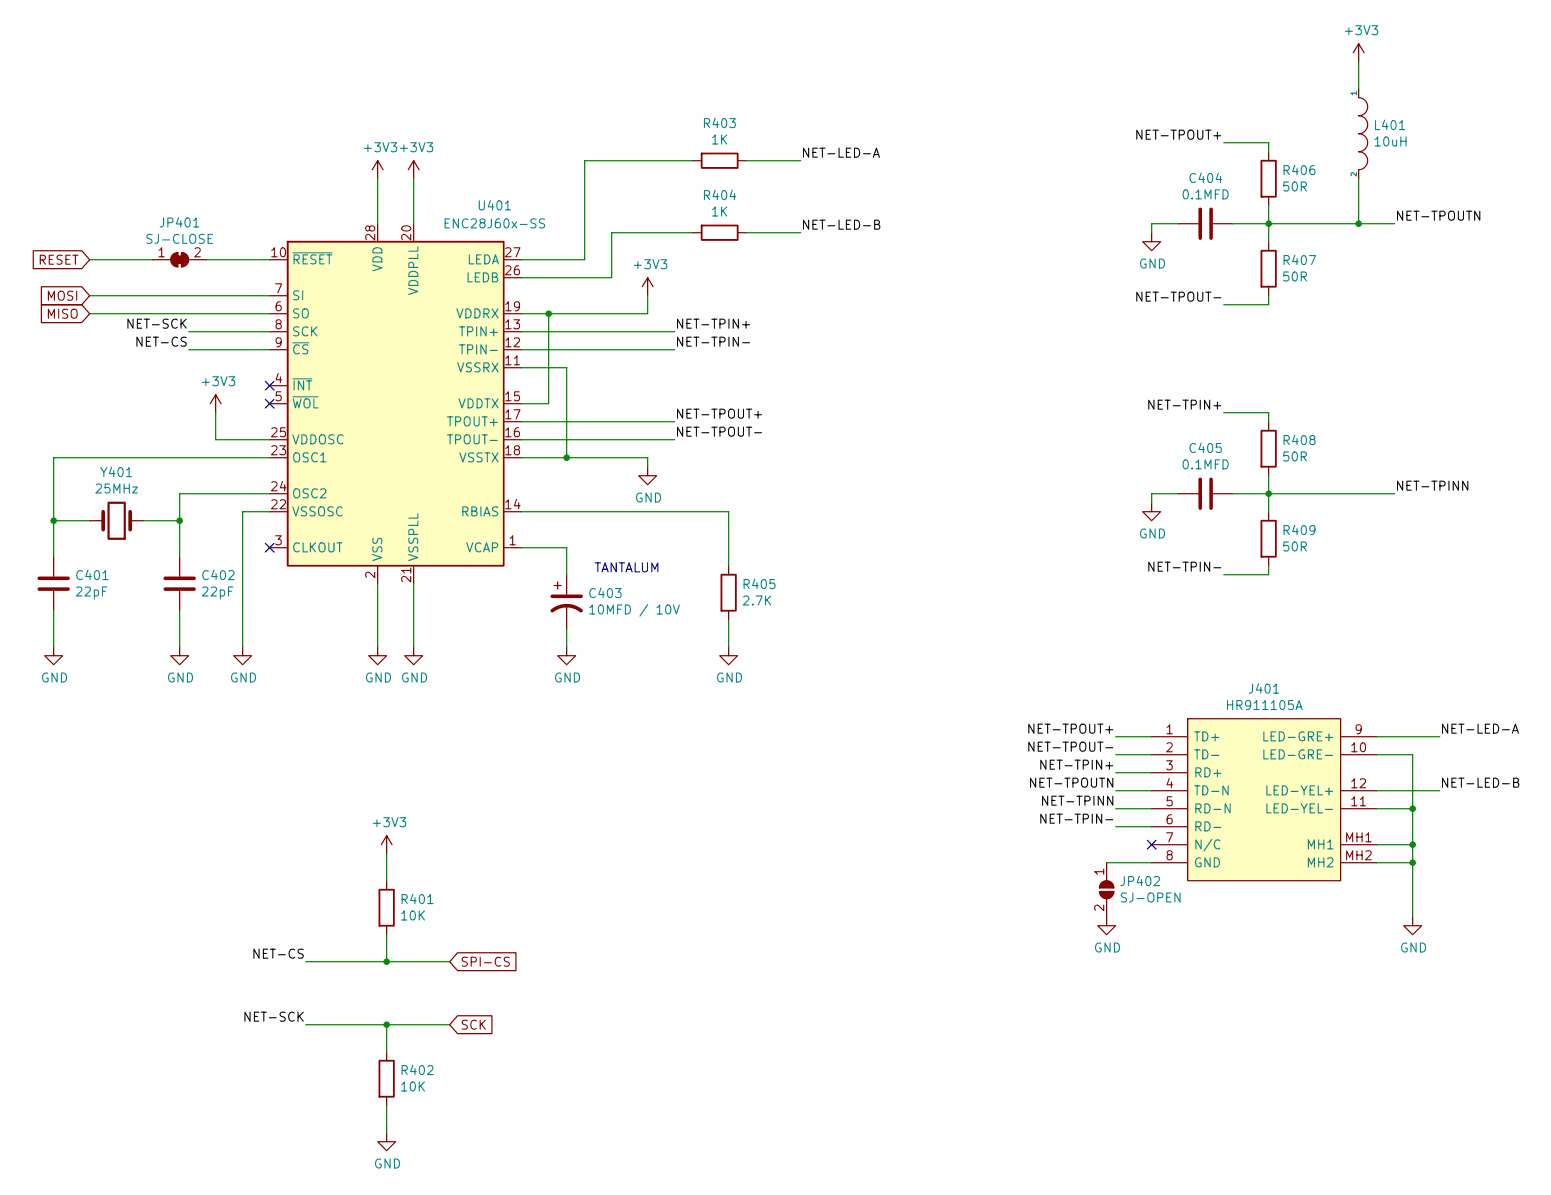
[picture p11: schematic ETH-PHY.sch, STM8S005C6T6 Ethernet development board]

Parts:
C401, C402: 22pF; C_0805_2012Metric_Pad1.18x1.45mm_HandSolder
C403: 10MFD / 10V; C_1206_3216Metric_Pad1.33x1.80mm_HandSolder
C404, C405: 0.1MFD; C_0805_2012Metric_Pad1.18x1.45mm_HandSolder
J401: HR911105A; Manufacturer_Part_Number HR911105A
JP401: SJ-CLOSE; SolderJumper-2_P1.3mm_Bridged2Bar_RoundedPad1.0x1.5mm
JP402: SJ-OPEN; SolderJumper-2_P1.3mm_Open_RoundedPad1.0x1.5mm
L401: 10uH; L_0805_2012Metric_Pad1.15x1.40mm_HandSolder
R401, R402: 10K; R_0805_2012Metric_Pad1.20x1.40mm_HandSolder
R403, R404: 1K; R_0805_2012Metric_Pad1.20x1.40mm_HandSolder
R405: 2.7K; R_0805_2012Metric_Pad1.20x1.40mm_HandSolder
R406, R407, R408, R409: 50R; R_0805_2012Metric_Pad1.20x1.40mm_HandSolder
U401: ENC28J60x-SS; SSOP-28_5.3x10.2mm_P0.65mm
Y401: 25MHz; Crystal_HC49-U_Vertical

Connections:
+3V3: L401.1, R401.1, U401.15 (VDDTX), U401.19 (VDDRX), U401.20 (VDDPLL), U401.25 (VDDOSC), U401.28 (VDD); also elsewhere on the board
/ETH-PHY/NET-LED-A: J401.9 (LED-GRE+), R403.1
/ETH-PHY/NET-LED-B: J401.12 (LED-YEL+), R404.1
/ETH-PHY/NET-TPIN+: J401.3 (RD+), R408.1, U401.13 (TPIN+)
/ETH-PHY/NET-TPIN-: J401.6 (RD-), R409.2, U401.12 (TPIN-)
/ETH-PHY/NET-TPINN: C405.1, J401.5 (RD-N), R408.2, R409.1
/ETH-PHY/NET-TPOUT+: J401.1 (TD+), R406.1, U401.17 (TPOUT+)
/ETH-PHY/NET-TPOUT-: J401.2 (TD-), R407.2, U401.16 (TPOUT-)
/ETH-PHY/NET-TPOUTN: C404.1, J401.4 (TD-N), L401.2, R406.2, R407.1
GND: C401.2, C402.2, C403.2, C404.2, C405.2, J401.10 (LED-GRE-), J401.11 (LED-YEL-), J401.MH1, J401.MH2, JP402.2 (B), R402.2, R405.2, U401.2 (VSS), U401.11 (VSSRX), U401.18 (VSSTX), U401.21 (VSSPLL), U401.22 (VSSOSC); also elsewhere on the board
MISO: U401.6 (SO); also elsewhere on the board
MOSI: U401.7 (SI); also elsewhere on the board
unnamed: C401.1, U401.23 (OSC1), Y401.2
unnamed: C402.1, U401.24 (OSC2), Y401.1
unnamed: C403.1, U401.1 (VCAP)
unnamed: J401.8 (GND), JP402.1 (A)
unnamed: JP401.2 (B), U401.10 (~RESET)
unnamed: R403.2, U401.27 (LEDA)
unnamed: R404.2, U401.26 (LEDB)
unnamed: R405.1, U401.14 (RBIAS)
RESET: JP401.1 (A); also elsewhere on the board
SCK: R402.1, U401.8 (SCK); also elsewhere on the board
SPI-CS: R401.2, U401.9 (~CS); also elsewhere on the board

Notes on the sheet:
TANTALUM

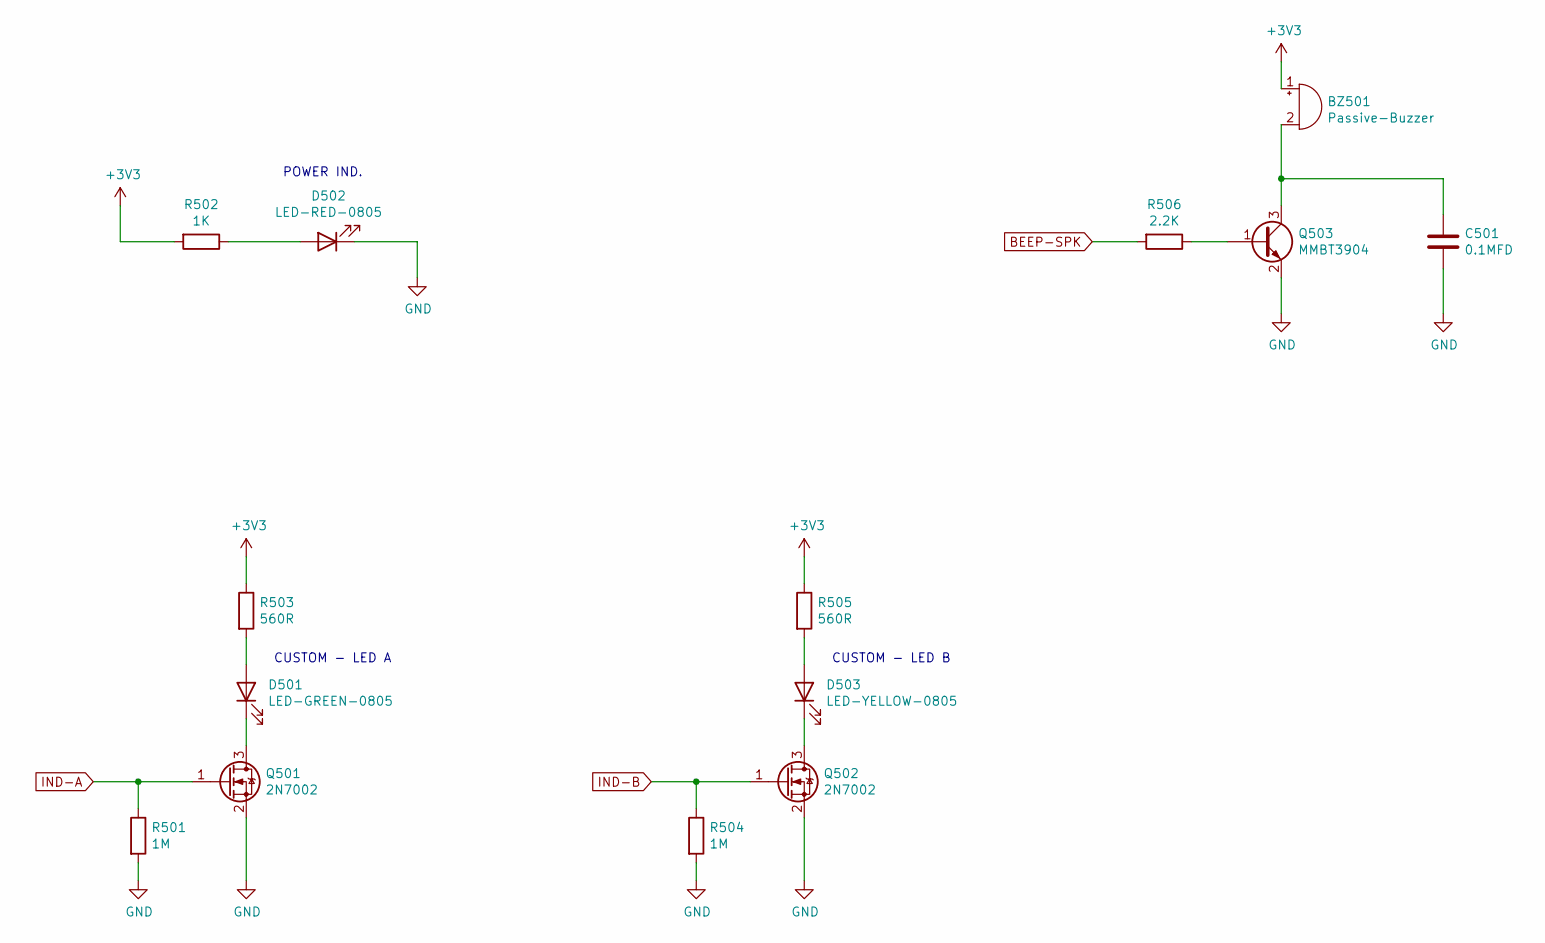
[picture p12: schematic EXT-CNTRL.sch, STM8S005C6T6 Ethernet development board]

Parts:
BZ501: Passive-Buzzer; Buzzer_12x9.5RM7.6
C501: 0.1MFD; C_0805_2012Metric_Pad1.18x1.45mm_HandSolder
D501: LED-GREEN-0805; LED_0805_2012Metric_Pad1.15x1.40mm_HandSolder
D502: LED-RED-0805; LED_0805_2012Metric_Pad1.15x1.40mm_HandSolder
D503: LED-YELLOW-0805; LED_0805_2012Metric_Pad1.15x1.40mm_HandSolder
Q501, Q502: 2N7002; SOT-23
Q503: MMBT3904; SOT-23
R501, R504: 1M; R_0805_2012Metric_Pad1.20x1.40mm_HandSolder
R502: 1K; R_0805_2012Metric_Pad1.20x1.40mm_HandSolder
R503, R505: 560R; R_0805_2012Metric_Pad1.20x1.40mm_HandSolder
R506: 2.2K; R_0805_2012Metric_Pad1.20x1.40mm_HandSolder

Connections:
+3V3: BZ501.1 (-), R502.2, R503.1, R505.1; also elsewhere on the board
BEEP-SPK: R506.2; also elsewhere on the board
GND: C501.2, D502.1 (K), Q501.2 (S), Q502.2 (S), Q503.2 (E), R501.2, R504.2; also elsewhere on the board
IND-A: Q501.1 (G), R501.1; also elsewhere on the board
IND-B: Q502.1 (G), R504.1; also elsewhere on the board
unnamed: BZ501.2 (+), C501.1, Q503.3 (C)
unnamed: D501.1 (K), Q501.3 (D)
unnamed: D501.2 (A), R503.2
unnamed: D502.2 (A), R502.1
unnamed: D503.1 (K), Q502.3 (D)
unnamed: D503.2 (A), R505.2
unnamed: Q503.1 (B), R506.1

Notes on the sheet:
CUSTOM - LED B
CUSTOM - LED A
POWER IND.

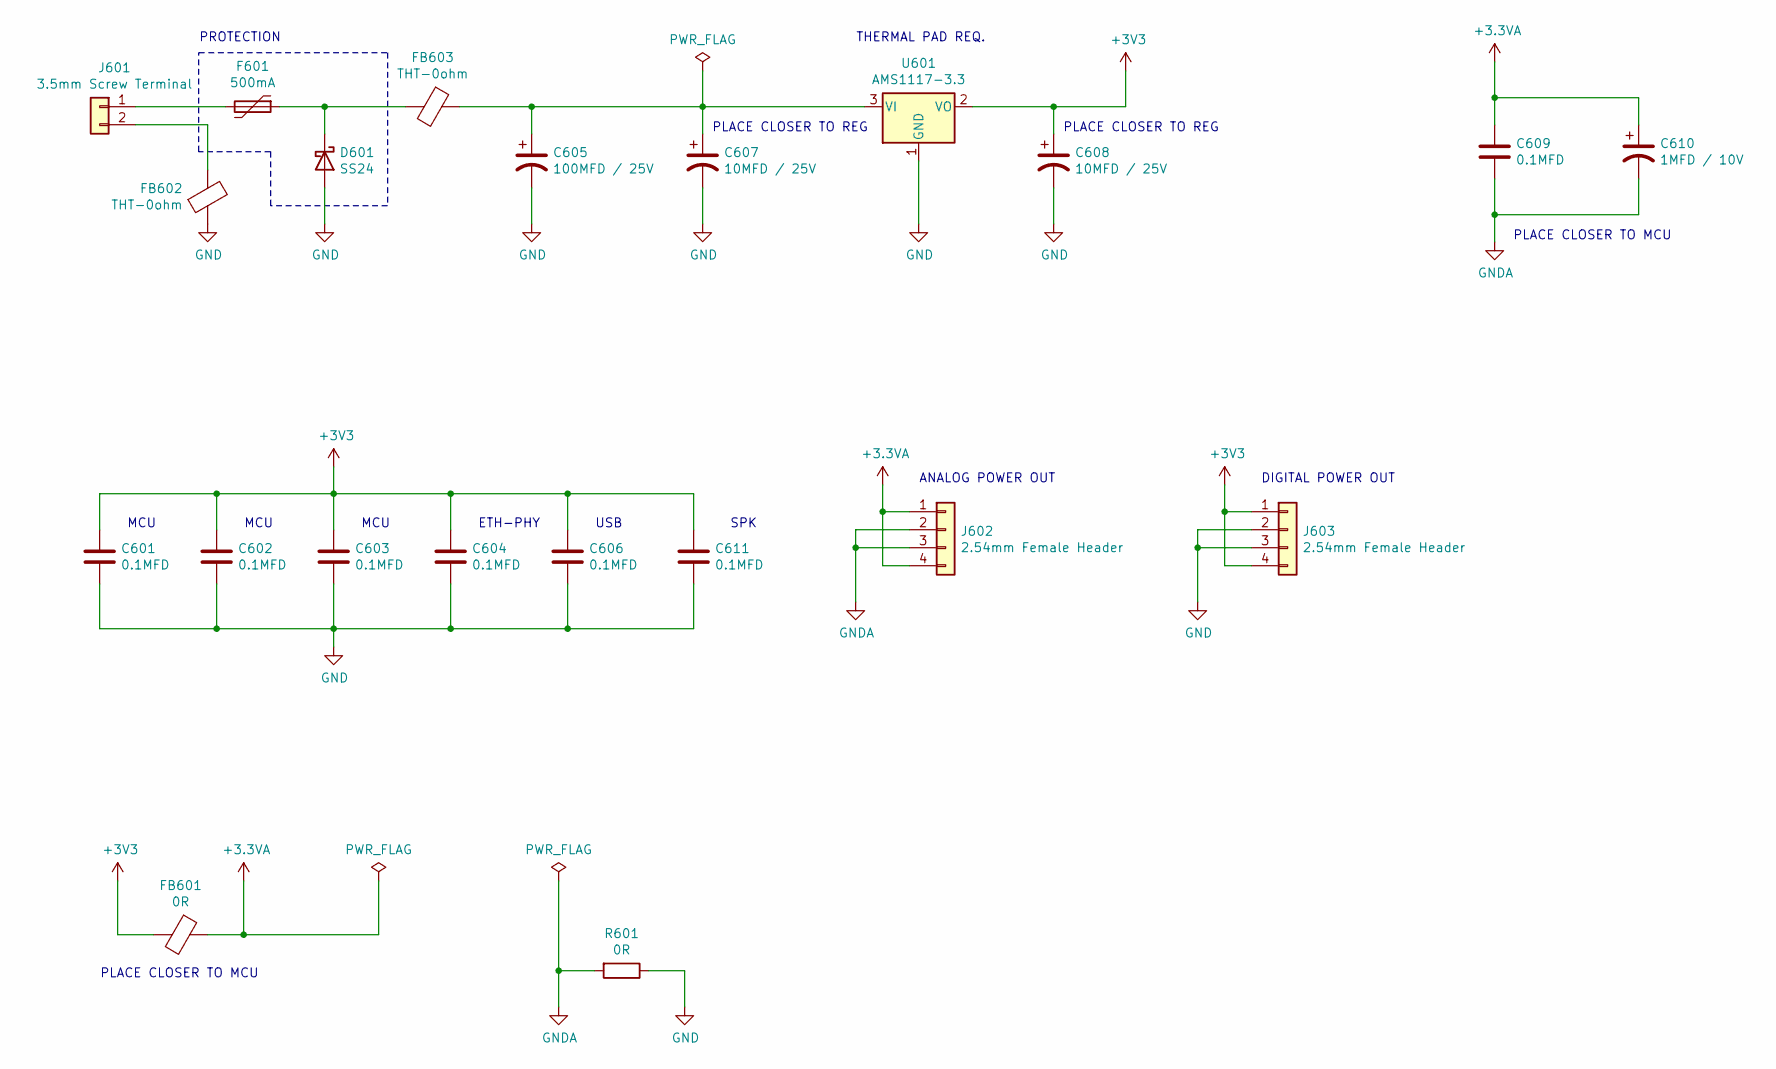
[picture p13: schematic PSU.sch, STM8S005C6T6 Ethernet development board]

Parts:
C601, C602, C603, C604, C606, C609, C611: 0.1MFD; C_0805_2012Metric_Pad1.18x1.45mm_HandSolder
C605: 100MFD / 25V; CP_Radial_D6.3mm_P2.50mm
C607, C608: 10MFD / 25V; CP_Radial_D5.0mm_P2.00mm
C610: 1MFD / 10V; C_0805_2012Metric_Pad1.18x1.45mm_HandSolder
D601: SS24; D_SMB_Handsoldering
F601: 500mA; Fuse_2816_7142Metric_Pad3.20x4.45mm_HandSolder
FB601: 0R; L_Axial_L6.6mm_D2.7mm_P10.16mm_Horizontal_Vishay_IM-2
FB602, FB603: THT-0ohm; L_Axial_L6.6mm_D2.7mm_P10.16mm_Horizontal_Vishay_IM-2
J601: 3.5mm Screw Terminal; PhoenixContact_MCV_1,5_2-G-3.5_1x02_P3.50mm_Vertical
J602, J603: 2.54mm Female Header; PinHeader_1x04_P2.54mm_Vertical
R601: 0R; R_0805_2012Metric_Pad1.20x1.40mm_HandSolder
U601: AMS1117-3.3; SOT-223-3_TabPin2

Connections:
+3.3VA: C609.1, C610.1, FB601.1, J602.1, J602.4; also elsewhere on the board
+3V3: C601.1, C602.1, C603.1, C604.1, C606.1, C608.1, C611.1, FB601.2, J603.1, J603.4, U601.2 (VO); also elsewhere on the board
GND: C601.2, C602.2, C603.2, C604.2, C605.2, C606.2, C607.2, C608.2, C611.2, D601.2 (A), FB602.1, J603.2, J603.3, R601.1, U601.1 (GND); also elsewhere on the board
GNDA: C609.2, C610.2, J602.2, J602.3, R601.2; also elsewhere on the board
unnamed: C605.1, C607.1, FB603.1, U601.3 (VI)
unnamed: D601.1 (K), F601.1, FB603.2
unnamed: F601.2, J601.1
unnamed: FB602.2, J601.2

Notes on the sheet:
PLACE CLOSER TO REG
PROTECTION
PLACE CLOSER TO MCU
ANALOG POWER OUT
DIGITAL POWER OUT
THERMAL PAD REQ.
MCU
ETH-PHY
USB
SPK

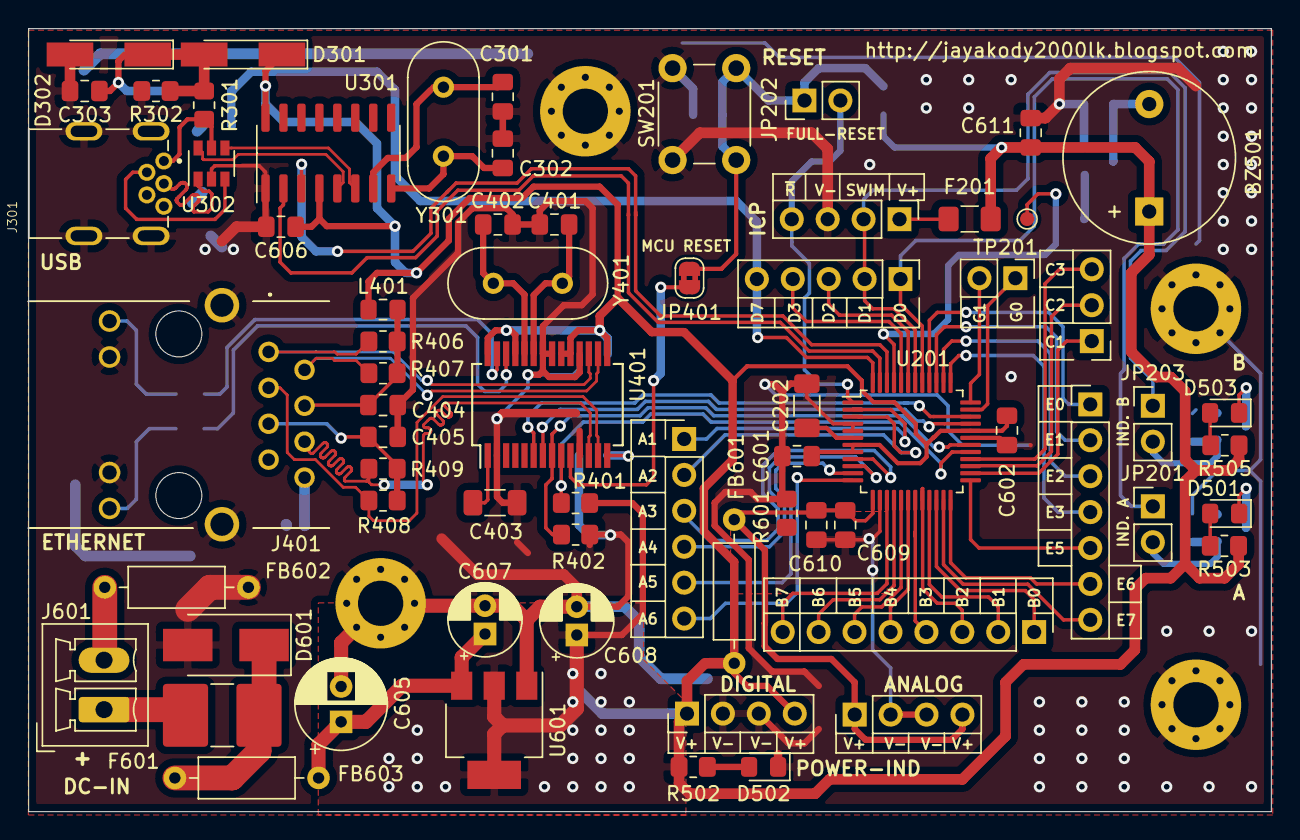
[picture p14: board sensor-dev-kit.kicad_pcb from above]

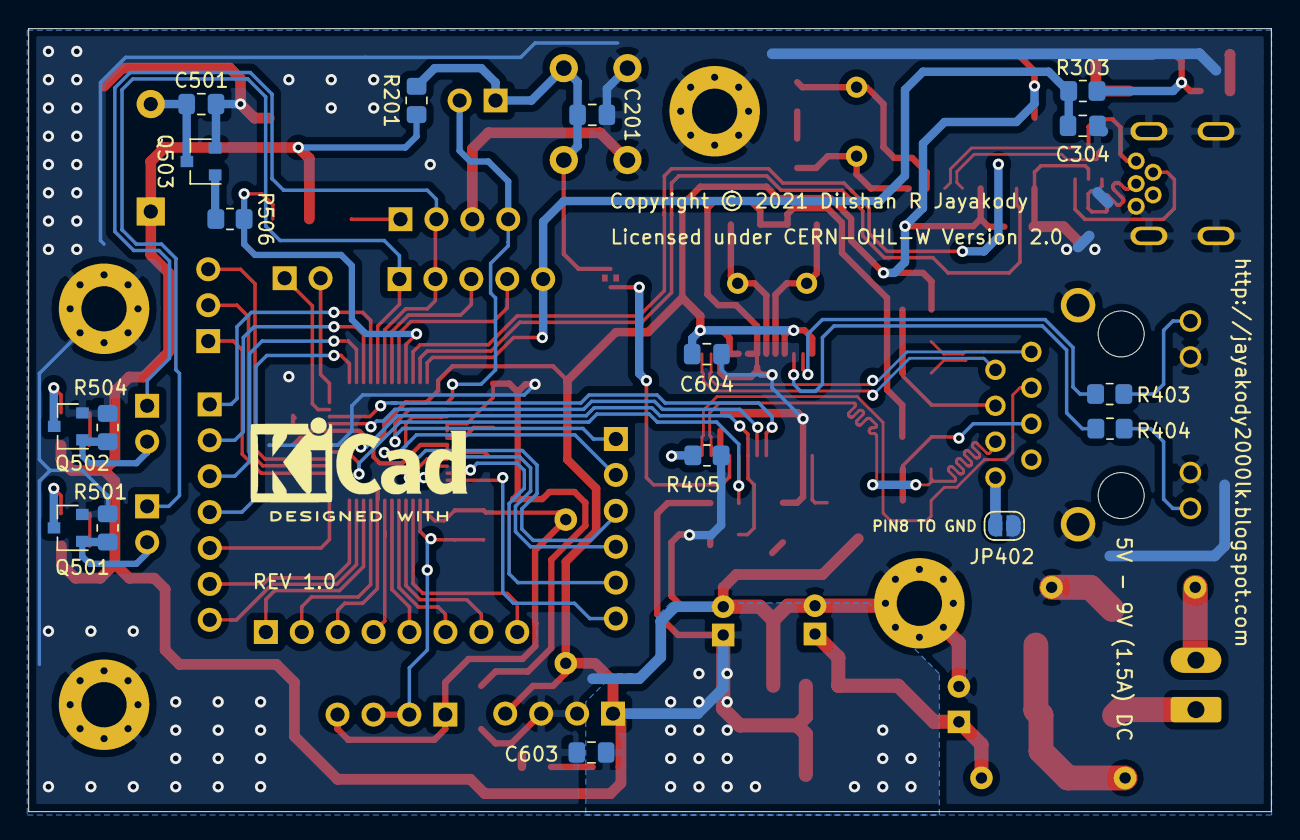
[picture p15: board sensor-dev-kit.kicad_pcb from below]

Board: 2 copper layers, 87.9 x 55.4 mm, 89 parts (17 on the bottom side), 83 nets.

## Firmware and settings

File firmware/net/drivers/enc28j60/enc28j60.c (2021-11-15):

//----------------------------------------------------------------------------
// ENC28J60 Eathernet driver for STM8 series MCUs.
// Copyright (C) 2021 Dilshan Jayakody.
//
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
#include "enc28j60.h"

#include "../../../include/stm8.h"
#include "../../../include/stm8-util.h"

#if defined(DEBUG_MSG) && defined(ENC28J60_LOG_MSG)
#include "../../../include/stm8-dbglog.h"
#endif

#include "../ethernet.h"

#if ETHERCARD_SEND_PIPELINING
    #define BREAKORCONTINUE retry=0; continue;
#else
    #define BREAKORCONTINUE break;
#endif

struct transmit_status_vector 
{
    unsigned char bytes[7];
};

static unsigned char Enc28j60Bank;
unsigned char enc28j60_broadcast_enabled = 0;

// Mute ``conditional flow changed by optimizer`` warning issued by SDCC.
#pragma disable_warning 110

void enc28j60InitSPI() 
{
    SPI_CR1 = 0;
    SPI_CR2 = 0;

    // Initialize CS as output with logic high.
    PC_DDR |= (1 << ENC28J60_CS_PIN);
    PC_CR1 |= (1 << ENC28J60_CS_PIN);
    PC_CR2 |= (1 << ENC28J60_CS_PIN);
    PC_ODR |= (1 << ENC28J60_CS_PIN);

    // Initialize MOSI as output with logic high.
    PC_DDR |= (1 << ENC28J60_MOSI_PIN);
    PC_CR1 |= (1 << ENC28J60_MOSI_PIN);
    PC_CR2 |= (1 << ENC28J60_MOSI_PIN);

    // Initialize MISO as input with pullup.
    PC_DDR &= ~(1 << ENC28J60_MISO_PIN);
    PC_CR1 |= (1 << ENC28J60_MISO_PIN);
    PC_CR2 &= ~(1 << ENC28J60_MISO_PIN);

    // Initialize SCK as output with logic high.
    PC_DDR |= (1 << ENC28J60_SCK_PIN);
    PC_CR1 |= (1 << ENC28J60_SCK_PIN);
    PC_CR2 |= (1 << ENC28J60_SCK_PIN);

    // Initialize SPI interface in master mode.
    SPI_CR2 = SPI_CR2_SSM | SPI_CR2_SSI;
    SPI_CR1 = SPI_CR1_MSTR | SPI_CR1_SPE;
}

unsigned char spiTransfer(unsigned char data) 
{
    SPI_DR = data;
    while ((SPI_SR & SPI_SR_RXNE) == 0);

    unsigned char  val = SPI_DR;
    while ((SPI_SR & SPI_SR_TXE) == 0);

    // Wait if SPI bus is busy. (to fix the lost of last bits at high speed clock rates.)
    while (SPI_SR & SPI_SR_BSY);  
    return val;
}

static void enableChip() 
{
    PC_ODR &= ~(1 << ENC28J60_CS_PIN);
}

static void disableChip() 
{
    while ((SPI_SR & SPI_SR_BSY));
    PC_ODR |= (1 << ENC28J60_CS_PIN);  
}

static unsigned char readOp(unsigned char op, unsigned char address) 
{
    enableChip();

    spiTransfer(op | (address & ADDR_MASK));

    if (address & 0x80)        
        spiTransfer(0x00);

    unsigned char result = spiTransfer(0x00);

    disableChip();
    return result;
}

static void writeOp(unsigned char op, unsigned char address, unsigned char data) 
{
    enableChip();
    spiTransfer(op | (address & ADDR_MASK));
    spiTransfer(data);
    disableChip();
}

static void readBuf(unsigned short len, unsigned char* data) 
{
    enableChip();

    if (len != 0) 
    {
        spiTransfer(ENC28J60_READ_BUF_MEM);

        while(len)
        {
            len--;
            *data = spiTransfer(0x00);              
            data++;
        }
    }

    disableChip();
}

static void writeBuf(unsigned short len, const unsigned char* data) 
{
    enableChip();

    if (len != 0) 
    {
        spiTransfer(ENC28J60_WRITE_BUF_MEM);

        while(len)
        {
            len--;
            spiTransfer(*data);
            data++;
        }
    }

    disableChip();
}

static void setBank(unsigned char address) 
{
    if ((address & BANK_MASK) != Enc28j60Bank) 
    {
        writeOp(ENC28J60_BIT_FIELD_CLR, ECON1, ECON1_BSEL1|ECON1_BSEL0);
        Enc28j60Bank = address & BANK_MASK;
        writeOp(ENC28J60_BIT_FIELD_SET, ECON1, Enc28j60Bank>>5);
    }
}

static unsigned char readRegByte(unsigned char address) 
{
    setBank(address);
    return readOp(ENC28J60_READ_CTRL_REG, address);
}

static unsigned short readReg(unsigned char address) 
{
    return readRegByte(address) + (readRegByte(address+1) << 8);
}

static void writeRegByte(unsigned char address, unsigned char data) 
{
    setBank(address);
    writeOp(ENC28J60_WRITE_CTRL_REG, address, data);
}

static void writeReg(unsigned char address, unsigned short data) 
{
    writeRegByte(address, data);
    writeRegByte(address + 1, data >> 8);
}

static unsigned short readPhyByte(unsigned char address) 
{
    writeRegByte(MIREGADR, address);
    writeRegByte(MICMD, MICMD_MIIRD);
    while (readRegByte(MISTAT) & MISTAT_BUSY);
    writeRegByte(MICMD, 0x00);
    return readRegByte((unsigned char)(MIRD+1));
}

static void writePhy(unsigned char address, unsigned short data) 
{
    writeRegByte(MIREGADR, address);
    writeReg(MIWR, data);
    while (readRegByte(MISTAT) & MISTAT_BUSY);
}

unsigned char enc28j60Init(const unsigned char* macaddr) 
{
    enc28j60InitSPI();
    disableChip();

    writeOp(ENC28J60_SOFT_RESET, 0, ENC28J60_SOFT_RESET);
    delay_ms(2);

    while (!(readOp(ENC28J60_READ_CTRL_REG, ESTAT) & ESTAT_CLKRDY));

    writeReg(ERXST, RXSTART_INIT);
    writeReg(ERXRDPT, RXSTART_INIT);
    writeReg(ERXND, RXSTOP_INIT);
    writeReg(ETXST, TXSTART_INIT);
    writeReg(ETXND, TXSTOP_INIT);

    writePhy(PHLCON, 0x476);

    writeRegByte(ERXFCON, ERXFCON_UCEN|ERXFCON_CRCEN|ERXFCON_PMEN|ERXFCON_BCEN);
    writeReg(EPMM0, 0x303f);
    writeReg(EPMCS, 0xf7f9);
    writeRegByte(MACON1, MACON1_MARXEN);
    writeOp(ENC28J60_BIT_FIELD_SET, MACON3, MACON3_PADCFG0|MACON3_TXCRCEN|MACON3_FRMLNEN);
    writeReg(MAIPG, 0x0C12);
    writeRegByte(MABBIPG, 0x12);
    writeReg(MAMXFL, MAX_FRAMELEN);
    writeRegByte(MAADR5, macaddr[0]);
    writeRegByte(MAADR4, macaddr[1]);
    writeRegByte(MAADR3, macaddr[2]);
    writeRegByte(MAADR2, macaddr[3]);
    writeRegByte(MAADR1, macaddr[4]);
    writeRegByte(MAADR0, macaddr[5]);
    writePhy(PHCON2, PHCON2_HDLDIS);

    setBank(ECON1);
    writeOp(ENC28J60_BIT_FIELD_SET, EIE, EIE_INTIE|EIE_PKTIE);
    writeOp(ENC28J60_BIT_FIELD_SET, ECON1, ECON1_RXEN);

    unsigned char rev = readRegByte(EREVID);
    // Microchip forgot to step the number on the silicon when they
    // released the revision B7. 6 is now rev B7. We still have
    // to see what they do when they release B8. At the moment
    // there is no B8 out yet.
    if (rev > 5) ++rev;
    return rev;
}

unsigned char enc28j60IsLinkUp() 
{
    return (readPhyByte(PHSTAT2) >> 2) & 1;
}

void enc28j60PacketSend(unsigned short len) 
{
    unsigned char retry = 0;

#if ETHERCARD_SEND_PIPELINING
    goto resume_last_transmission;
#endif

#if defined(DEBUG_MSG) && defined(ENC28J60_LOG_MSG)

    debugPrintNewLine();
    debugPrintLn("------- Packet --------");

    unsigned char logPos = 0;
    for(logPos = 0; logPos < len; logPos++)
    {
        debugPrintNum(ethernet_buffer[logPos]);
        debugPrint(" ");
        if((logPos > 0) && ((logPos % 8) == 0))
        {
            debugPrintNewLine();
        }
    }

    debugPrintNewLine();
    debugPrintLn("-----------------------");
    debugPrintNewLine();
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

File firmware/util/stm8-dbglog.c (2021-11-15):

//----------------------------------------------------------------------------
// STM8S UART based debugging routines.
// Copyright (C) 2021 Dilshan Jayakody.
//
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
#include "../include/stm8.h"
#include "../include/stm8-uart.h"
#include "../include/stm8-dbglog.h"
#include "../net/net.h"

#ifdef DEBUG_MSG

// Print only the specified string.
void debugPrint(const unsigned char* msg)
{
    unsigned char msgPos = 0;
    
    while((msg[msgPos] != 0) && (msgPos < 0xFE))
    {
        uartWrite(msg[msgPos++]);        
    }
}

// Print specified string and move to new line.
void debugPrintLn(const unsigned char* msg)
{
    debugPrint(msg);

    // Move to new line after the message print.
    uartWrite(0x0A);
    uartWrite(0x0D);
}

// Print unsigned short number specified in the parameters.
void debugPrintNum(unsigned short val)
{
    unsigned char str[6] = {0,0,0,0,0,0};
    unsigned char pos = 0;

    do
    {
        str[pos] = (val % 10) + 0x30;
        val = val / 10;
        pos++;
    }
    while(val > 0);

    for(pos = 6; pos != 0xFF; pos--)
    {
        if(str[pos] != 0)
        {
            uartWrite(str[pos]);
        }
    }
}

void debugPrintIPAddress(const unsigned char *ip)
{
    unsigned char pos = 0;
    for(pos = 0; pos < IP_LEN; pos++)
    {
        debugPrintNum(ip[pos]);
        
        if(pos != (IP_LEN - 1))        
            uartWrite('.');
    }
}

void debugPrintMACAddress(const unsigned char *mac)
{
    unsigned char pos = 0;
    for(pos = 0; pos < ETH_LEN; pos++)
    {
        debugPrintNum(mac[pos]);

        if(pos != (ETH_LEN - 1))
            uartWrite(':');
    }
}

void debugPrintNewLine()
{
    uartWrite(0x0A);
    uartWrite(0x0D);
}

#else

// Debug logging is turn-off. Set DEBUG_MSG to turn on the debug logging.

void debugPrint(const unsigned char* msg){}
void debugPrintLn(const unsigned char* msg){}
void debugPrintNum(unsigned short num){}
void debugPrintNewLine(){}

void debugPrintIPAddress(const unsigned char *ip){}
void debugPrintMACAddress(const unsigned char *mac){}

#endif

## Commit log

2021-11-14 Add initial version of development board design files.
    [ETH-PHY.sch, EXT-CNTRL.sch, MCU-SYS.sch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]
2021-11-15 Fix source code formating issues in ENC28J60 driver.
    [enc28j60.c]
2021-11-15 Add image of the IoT development board.
2021-11-15 Add BOM files in PDF and LibreOffice Calc formats.
    [eth-sensor-development-kit-bom.ods]

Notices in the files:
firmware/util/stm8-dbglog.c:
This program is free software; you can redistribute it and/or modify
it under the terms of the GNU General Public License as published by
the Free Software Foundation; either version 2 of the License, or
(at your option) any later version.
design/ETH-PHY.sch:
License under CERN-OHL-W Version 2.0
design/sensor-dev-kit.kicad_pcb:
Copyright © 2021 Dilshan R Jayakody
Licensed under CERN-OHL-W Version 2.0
